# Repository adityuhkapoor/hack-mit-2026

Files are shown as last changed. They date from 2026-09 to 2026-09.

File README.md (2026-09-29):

# Nimbus

An experimental camera built at HackMIT 2026. Nimbus keeps the photographed
subject unchanged while using light, temperature, motion, sound, and weather
data to generate a new setting around them.

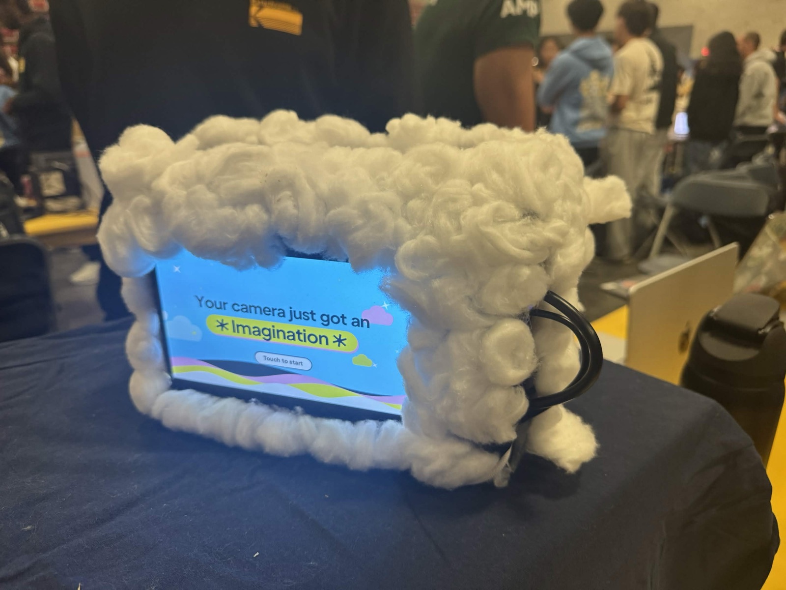
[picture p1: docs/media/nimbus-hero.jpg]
Nimbus running at HackMIT 2026


**[Watch the demo](https://youtu.be/b3_kws8iIpU)** ·
**[Instagram](https://www.instagram.com/nimbus_hackmit2026/)** ·
**[Web interface](web/)**

The prototype runs across a Raspberry Pi 4, an Arduino UNO Q, and an ASUS
Ascent GX10. It supports voice capture, searchable photo metadata, QR sharing,
printing, and pixel-level verification that the protected subject was preserved.

The app has two modes:

- **AI Camera:** takes a photo, chooses a design based on what's in it, and sends it
  to a GPU server to generate the result. The pipeline uses a subject mask to keep
  the selected subject from the original photo while changing the area around it.
- **Visa Buy:** takes an unedited photo, identifies the item or dish, and searches
  for shopping options. The app includes a Visa checkout flow; purchase completion
  is not covered by our current hardware tests.

You can browse saved photos, search them by voice or text, and open a photo link
on your phone by scanning a QR code. Voice, sharing and Instagram posting require
their respective services and credentials. Automatic Instagram posting is enabled
by default; set `NIMBUS_AUTO_POST=0` for testing.

The Raspberry Pi runs the screen and webcam. An Arduino UNO Q supplies thermal
readings and button input, and an ASUS GPU computer processes AI captures over
the network. Sensor readings are included with captures; the current AI Camera
mode chooses its design from the photo's content.

## Repository guide

| Where | What |
|---|---|
| [docs/BUILD_LOG.md](docs/BUILD_LOG.md) | Photos and notes from loose electronics through the HackMIT prototype and printable enclosure design |
| [docs/DESIGN.md](docs/DESIGN.md) | Original design notes, including earlier mode names and sensor-effect concepts |
| [TEAM_HARDWARE_RUNBOOK.md](TEAM_HARDWARE_RUNBOOK.md) | **Hardware handoff**: touchscreen wiring, camera bring-up, board roles, ASUS/Pi networking, verified behavior, and open gaps |
| [device/](device/) | The camera app (voice, screen, d-pad, tagging, search). Runs on the Raspberry Pi rig; Mac development and legacy UNO Q mode are also supported |
| [pipeline/](pipeline/) | The image pipeline and API (`nimbus`), deployed on the GPU box |
| [infra/elastic/](infra/elastic/) | Elasticsearch for photo search |
| [docs/HANDOFF.md](docs/HANDOFF.md) | Deployment handoff notes; check dates before relying on host or service status |
| [docs/TRACKS.md](docs/TRACKS.md) | Sponsor tracks: what to show a judge for each, and the demo order |
| [docs/demo/](docs/demo/) | Demo renders |

Quick start on a Mac: see [device/README.md](device/README.md) (`uv run python -m nimbus_cam --mac`).

Never commit credentials, Tailscale authentication links, Wi-Fi passwords,
camera tokens, or private user photos.

## Current rig and performance

The Raspberry Pi 4 runs the touchscreen app and USB C270 webcam. The Arduino UNO Q
provides thermal readings and buttons; the ASUS GPU computer runs the AI service.
See [device setup](device/README.md) and [network recovery](device/NETWORK_RECOVERY.md).

The tested Pi launcher selects the SDL2 presenter at a 24 FPS target. Steady home-screen
callback throughput measured approximately 23.9–24.0 FPS; capture/review transitions
still have occasional hitches. This is app callback throughput, not measured display
scanout or camera-to-screen latency. A fresh checkout defaults to Tk at 15 FPS until
configured. See [measurements and limitations](device/FRAME_PACING_RESULTS.md).

An intermittent capture error (`Server disconnected without sending a response`)
remains under investigation. Experimental camera buffering changes are not on main
and have no verified hardware speedup yet.

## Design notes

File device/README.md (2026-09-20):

# Nimbus camera app

The current rig uses a Raspberry Pi 4 for the Python app, touchscreen and USB webcam,
an Arduino UNO Q for thermal readings and buttons, and an ASUS GPU computer for AI
capture processing. Mac development uses simulated sensors. The older standalone
UNO Q App Lab files (`sketch/`, `python/`, `app.yaml`) are a legacy path, not the
current Pi deployment instructions.

## The rig (Raspberry Pi 4 + Arduino UNO Q + C270 + 1024x600 touch panel)

| Part | Where | Feeds |
|---|---|---|
| MLX90640 thermal array | behind the UNO Q, I2C `0x08` (12 chunks, ~3 fps) | temperature → hue, frame change → motion → blur |
| C270 webcam | USB | the picture, and the light level → grain |
| C270 microphone | USB (ALSA card 3) | sound → saturation, and your voice |
| Speaker | the Pi's 3.5 mm jack (or HDMI) | the camera's voice |
| Touch panel | HDMI + USB touch | the screen and its buttons |
| Local weather | Open-Meteo | humidity → diffusion, wind, cloud (labelled "(web)") |

**The four buttons** are on the **UNO Q's** digital pins (active-low to ground; the sketch enables the
pull-ups) and reach the Pi over the same I2C link as the thermal array (command `0x07`, see
[unoq/nimbus_unoq.ino](unoq/nimbus_unoq.ino)). The Pi names them with
`NIMBUS_BUTTONS="shutter=4,mode=5,talk=6,browse=7"` and turns them on with `NIMBUS_I2C_BUTTONS=1`:

| Button | Does |
|---|---|
| `shutter` (D4) | take a photo |
| `mode` | switch mode: AI Camera ⇄ Visa Buy |
| `talk` | hold to speak to the camera |
| `browse` | next photo / open the gallery |

Only D4 is named so far. **A press on an unnamed pin is logged** (`[buttons] unnamed pin D9 pressed`) — press
each button once while watching `~/nimbus-run.log`, put the numbers in `NIMBUS_BUTTONS` in
`~/start_nimbus.sh`, and restart. The configured labwc autostart calls that launcher. (Buttons straight on the Pi's GPIO still
work too: `NIMBUS_GPIO=1`, `NIMBUS_PINS="shutter=17,mode=27,talk=22"`.)

### Reflashing the UNO Q

There is no Arduino IDE in the loop: the sketch is built and flashed **from the UNO Q's own Linux**, reached
over ADB from the Pi (the board is on the Pi's USB).

```bash
ssh pi
adb shell                                                    # user: arduino
arduino-cli lib install "Adafruit MLX90640"                  # once
python3 patch_mlx90640.py ~/Arduino/libraries/Adafruit_MLX90640/Adafruit_MLX90640.cpp   # once, see unoq/patches
cd ~/nimbus_unoq && arduino-cli compile --fqbn arduino:zephyr:unoq . \
  && arduino-cli upload --fqbn arduino:zephyr:unoq -p 192.168.8.122 --upload-field password=arduino .
```

(`adb push` the sketch and the patch script from the Pi first; the upload address is the board's own wlan0,
`arduino-cli board list` prints it.) The MCU restarts ~30 s after the upload finishes. Its `Serial` output is
`/dev/ttyACM0` on the Pi: `sudo timeout 5 cat /dev/ttyACM0` shows frames and `buttons=0x..` on every press.

**Why the patch:** the Zephyr core's `Wire` always sends a STOP after the address write, and the MLX90640
needs a repeated start, so every read came back from the wrong address and every pixel was NaN. The patch
makes the driver read through Zephyr's `i2c_write_read()`.

## Run the camera on a Mac (no hardware needed)

```bash
(cd infra/elastic && docker compose up -d)          # photo search (optional: falls back to a local index)
cd device && uv sync
uv run python -m nimbus_cam.agent                # once: creates the ElevenLabs agent (needs both keys)
uv run python -m nimbus_cam --mac                # screen + voice + webcam + simulated sensors
```

| Mode | Command |
|---|---|
| A still instead of the webcam | `--image ../pipeline/eval/photos/64.jpg` |
| Type to the camera (Muse, no mic, no ElevenLabs) | `--text` |
| Tools only, no screen: a test script | `--script "fog; take_photo; wait; search_photos query=fog"` |
| Skip Elasticsearch | `--local-library` |

Keys: ←/→ mode · space shutter · **hold T to talk** · ↑/↓ browse · P send to phone (QR code) · I post to Instagram · R print (or the PRINT button on the photo screen) ·
Esc viewfinder · F/H simulated fog/heat.

On macOS, secrets can come from Keychain or environment variables. On the Pi, the configured launcher sources the existing `/etc/nimbus.env`; keep it and the local voice-agent configuration out of Git.

| Keychain service | Environment variable | Status |
|---|---|---|
| `meta-model-api-key` | `MODEL_API_KEY` | required for model calls |
| `elevenlabs-api-key` | `ELEVENLABS_API_KEY` | needed for voice |
| `ig-token` | `IG_TOKEN` | needed to post (the account id is looked up from it) |

```bash
security add-generic-password -s elevenlabs-api-key -a $USER -w '<key>' -T /usr/bin/security -U
```

Tests: `uv run pytest` (offline; no keys, models or network needed).

Instagram needs a professional (business or creator) Instagram account and one token from the Meta app dashboard (Instagram API with Instagram Login). Check it with `uv run python -m nimbus_cam.instagram`. Token scope:
`instagram_content_publish`. The card image is what gets posted.

## On the Pi rig (Raspberry Pi 4 + Arduino UNO Q + C270)

```bash
rsync -a --exclude .venv --exclude .git ./ raspi4:~/nimbus/     # from the repository root; requires your SSH alias
ssh raspi4 'cd ~/nimbus && python3 -m venv .venv && .venv/bin/pip install -e pipeline -e device'
ssh raspi4 'sudo apt-get install -y libportaudio2'      # the webcam microphone
ssh raspi4 'cd ~/nimbus/device && NIMBUS_SEG=human ../.venv/bin/python -m nimbus_cam --pi'
```

`--pi` reads the MLX90640 thermal array through the UNO Q on I2C 0x08 (temperature, and motion from the
change between frames), the light level from the camera frame, and sound from the webcam microphone.
Humidity, wind and cloud come from the local weather and are labelled "(web)" on the card.
`NIMBUS_SEG=human` picks the light segmentation model, which the Pi can actually run.

Before using the Elasticsearch library, download and verify its search model while
the network is available:

```bash
cd device
uv run python -c 'from nimbus_cam.library import embed; print(embed(["setup check"]).shape)'
```

The model stays in `~/.nimbus/camera/models` (or `NIMBUS_EMBED_CACHE`), survives
reboots, and loads offline when cached. Run this as the camera user with the same
`NIMBUS_CAM_HOME` setting as the app. A missing model still requires a first download;
capture currently waits for library indexing before showing review.

## Tested touchscreen configuration

The touchscreen starts on the animated Nimbus welcome screen. Touch anywhere to
enter the camera through a parting cloud curtain; that touch does not take a photo.
The clouds wait briefly for a fresh preview frame, with a bounded timeout if the
camera is unavailable. The **IDLE** button in the
top-right corner of the viewfinder returns to the welcome screen. While idle,
preview decoding and shutter actions are paused. The camera connection and other
app services remain initialized for quick resume. Set `NIMBUS_START_IDLE=0` to
start directly in the viewfinder for automated capture tests. Script mode is
unaffected. The IDLE button is unavailable during capture.

The existing Pi deployment uses `~/start_nimbus.sh`, called by labwc autostart.
It selects `NIMBUS_UI_BACKEND=sdl`, `NIMBUS_UI_FPS=24`,
`SDL_VIDEODRIVER=wayland` and `NIMBUS_UI_FRAME_STATS=1`. The SDL presenter must
be [built separately](native_presenter/README.md); installing Python packages
alone does not build it. Tk is still needed for the event loop. SDL initialization
failure falls back to Tk. Without configuration the source defaults to Tk at 15 FPS.

Measured steady home-screen callback throughput was roughly 23.9–24.0 FPS.
Transitions can still hitch; these measurements do not establish physical display
FPS or webcam latency. See [full results](FRAME_PACING_RESULTS.md).

The configured Pi uses `NIMBUS_API=http://127.0.0.1:18000` and
`NIMBUS_ES_URL=http://127.0.0.1:19200` through its persistent SSH tunnel to ASUS.
These endpoints require the tunnel and its separately provisioned keys; they do
not work on a fresh machine just by setting environment variables. See
[network recovery and verification](NETWORK_RECOVERY.md). The Pi and ASUS can
use different networks if both can reach their tailnet.

Automatic Instagram posting defaults to enabled. For capture QA, set
`NIMBUS_AUTO_POST=0` in the process environment after loading configuration.
An intermittent `Server disconnected without sending a response` capture failure
remains unresolved. Camera-buffer experiments are not included in main.

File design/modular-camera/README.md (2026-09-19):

# Nimbus modular camera — mechanical prototype R01

Printable modular chassis around the existing screen holder. Designed for the HackMIT Bambu A1 / P1S machines listed at <https://hardware.hackmit.org/3d-prints>: 256 × 256 × 256 mm, 0.4 mm nozzle, PLA (checked September 19, 2026). **Nothing has been submitted for printing.**

## What this is

A roomy, serviceable assembly: rear screen frame, floor, two open sides, removable roof, replaceable webcam front, electronics shelf, webcam cradle, battery cradle, and interchangeable sensor carriers. Separate parts join with through-bolts and nuts. These are **not snap-fit joints**. The old screen-holder R02 is reused unchanged; do not print another if you already have it.

Main shell: approximately **224 W × 188 D × 180 H mm**, before protruding sensors, fasteners, screen washers and cables. This prioritizes hackathon access and modularity over a compact polished camera. Open sides are deliberate cable/service openings, not a sealed or drop-resistant enclosure.

In scope:

- Rear touchscreen, using your measured body and mounting-tab dimensions.
- Raspberry Pi **4B** and Arduino UNO Q, both accommodated on one removable shelf. Either can be omitted. Mechanical accommodation does not establish their software roles or electrical compatibility.
- Anker **A110D** power bank, removable and strapped at the bottom.
- Logitech **C270**, retained with its original clip and adjustable straps/padding.
- Up to five external sensor/control carriers: proposed roof Buttons, Light, Movement; front Distance and thermal/spare. Only install modules you actually need.

Not included: ESP32 / BOX-3 (explicitly removed), internal ASUS, printer, TP-Link hub, or a speaker. ASUS can remain external/networked. The Logitech has a microphone, not a speaker; voice output needs a separate later provision.

## Files

- `nimbus-modular-camera.blend`: assembled editable Blender model, including clearly named reference hardware.
- `build.py`: parameterized Python construction source for Blender 5.2; millimetres. Run `blender -b --python build.py` from an extracted package. `inputs/` contains the original screen-frame/washer meshes needed to rebuild.
- `stl/`: **only printed parts**, individually exported in intended print orientation. No electronics are included in these STLs. Import at 100%, millimetres.
- `PRINT_MANIFEST.md`: exact copies and exported dimensions.
- `ASSEMBLY.md`: staged print and assembly instructions, fasteners and outstanding checks.
- `SOURCES.md`: sources, measurements and assumptions.
- `print-manifest.json`: per-part manifold, connected-solid, volume, triangle and dimension checks.
- `clearance-checks.json`: rigid-part and reference-envelope interference checks.
- `mounting-coordinates.json`: the board and screen interface coordinates.
- `assembled-front.png`, `assembled-rear.png`, `cutaway.png`, `exploded.png`: CAD renders, not photos of an assembled device. Colored blocks are approximate hardware envelopes; logos/text are reference-only and are not embossed in the printable meshes.

This is mesh-based CAD with a reproducible generator, not a STEP/B-rep model. Package includes the `.blend`, source, STLs, documentation, references and renders.

## Validation and limits

Every exported part passed checks for a single connected solid, zero non-manifold edges, positive volume, a nonempty binary STL and dimensions within 0.002 mm of the source mesh. Every individual part fits the published printer volume. Modeled mating parts and conservative hardware envelopes show no solid intersections above the script's 0.1 mm³ reporting threshold.

**Physical fit, load strength, cable bending, slicer behavior, print duration, cooling and the complete power budget are not validated.** The model is ready for a staged fit prototype, not an assertion that all hardware can be enclosed and battery-powered without further testing. Start with the screen frame and hole coupon, not an unattended full print batch.

## Electrical scope is unchanged

This enclosure does not solve power distribution. The photographed A110D label gives a combined **5 V / 3 A (15 W)** output limit in multi-port use. Do not infer the complete Pi + UNO Q + screen + camera system can run from it merely because all components fit. Leave wall-power options accessible and test the intended wiring under load before relying on battery operation. No improvised battery wiring, GPIO power feeds or USB power backfeeding are part of this design.

Boards need insulating spacers, connectors need strain relief, and the power bank must remain removable without being squeezed. Keep ventilation clear. Do not use this prototype as a load-bearing shoulder-strap case until the assembled joints have been checked under the actual weight.

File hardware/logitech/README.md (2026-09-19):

# Logitech C270 camera module — Mac bench prototype

This is Aditya's tested local Camera Studio prototype, published separately from
the existing Nimbus `device/`, `pipeline/`, and `web/` apps. It does not replace
them or claim that their hardware integration is complete.

## What is included

- `server.py`: Logitech capture backend (`Camera`), localhost HTTP API, original
  capture storage, gallery, local effects, optional provider hooks.
- `web/`: preview, touch-friendly shutter, rotate/mirror, effect selection,
  original/result comparison and downloads. Spacebar can trigger capture.
- `arduino_link.py`: optional UNO Q discovery over ADB and capture LED feedback.
  This is not physical shutter firmware or a sensor driver.
- Tests, dependency list and a credential-free `.env.example`.

No real captures, API keys, firmware dumps, personal photos or account credentials
are included. Local `captures/` and `.env` files are ignored.

## Run on macOS

Requirements: Python 3.10+, FFmpeg with AVFoundation support, and a USB-connected
Logitech C270. The implementation currently uses AVFoundation, not Linux V4L2.
Install FFmpeg with your normal package manager if absent. ADB is optional.

```sh
cd hardware/logitech
python3 -m venv .venv
source .venv/bin/activate
python3 -m pip install -r requirements.txt
python3 server.py
```

Open <http://127.0.0.1:8765>, grant macOS camera access to the process that requests
it, and click Connect camera. If another camera app owns the camera, close it.
The default device name is `C270 HD WEBCAM`; set `CAMERA_NAME` in the environment
or a local `.env` if the device is named differently. `PORT` can override 8765.
There is no need to create `.env` or configure cloud credentials for local use.

The backend requests 1280x720 at 30 fps; this is a requested mode, not a guaranteed
achieved rate. The existing `preview_fps` status field is hard-coded, and the UI
polls JPEG frames every 250 ms. Do not use that field as a measured frame rate.

## Verification and limitations

```sh
python3 -m unittest test_server.py test_arduino_link.py
```

All 10 tests passed when published. They use synthetic images/mocked hardware;
they do not establish fresh USB, touchscreen, cloud API or Pi compatibility.
Earlier physical bench testing demonstrated C270 live capture on the Mac.

- Linux/Pi/UNO Q camera hosting still needs a V4L2 (or equivalent) backend.
- Local Enhance/Noir/Dream/cards are local image processing, not generative AI.
- OpenAI editing and ElevenLabs speech hooks are unverified. The inherited image
  model setting is not validated; explicitly configure a supported model before
  enabling provider calls. Supplying keys and using those actions sends image/
  prompt or text to the provider and may incur costs. Speech plays on the browser
  host; this does not provide BOX-3 speaker transport.
- With no speech API key, browser speech synthesis may be used; behavior and
  offline support depend on the browser/OS voice engine.
- The UNO Q adapter polls ADB devices for the UNO Q user-LED interface and, on
  capture, briefly writes that LED only if its trigger is `none`, then restores
  brightness. No sketch is flashed. Disconnect the board/omit ADB if undesired.
- `/api/sensors` is an ingestion boundary only. No physical sensor readings or
  shutter input are implemented here; stale readings are omitted.
- Preview stays in RAM until explicit capture. Captured originals and edits are
  stored locally. A watchdog releases the camera after 90 seconds without camera
  activity; status polling alone does not count as frame activity.
- Localhost binding, Host/Origin checks and a per-process action token are present.
  They are not remote-service authentication. Do not change the bind address or
  expose this prototype directly to venue Wi-Fi/the internet.

## Integration boundary

Reuse `Camera.start()`, `snapshot()`, `status()` and `stop()` as the initial
acquisition contract. Keep the platform-specific FFmpeg command behind this
boundary when adding Linux support. `capture()` preserves the original and
freezes available sensor values; both future physical-shutter and UI events
should invoke the same serialized capture action.

GET routes: `/api/status`, `/api/frame`, `/api/gallery`.
POST routes: `/api/camera/start`, `/api/camera/stop`, `/api/capture`, `/api/render`,
`/api/sensors`, `/api/speech`. POST calls require `X-Camera-Token` from the local
page's `camera-token` meta element. Prefer the included UI for bench testing.

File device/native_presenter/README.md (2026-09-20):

# Nimbus native presenter prototype

This opt-in prototype keeps Nimbus rendering in Python/Pillow and replaces only
the final Tk image handoff with a persistent SDL2 streaming texture. `nimbus_cam.ui` integrates it when
`NIMBUS_UI_BACKEND=sdl` is set, and falls back to Tk if initialization fails.
The tested Pi launcher targets 24 FPS with `NIMBUS_UI_FPS=24` and
`SDL_VIDEODRIVER=wayland`; generic defaults remain Tk and 15 FPS.

Build on a machine with SDL2 development headers:

```bash
cd device/native_presenter
cmake -S . -B build -DCMAKE_BUILD_TYPE=Release
cmake --build build --config Release
```

Debian/Raspberry Pi OS provides the headers in `libsdl2-dev`. Installing that
package on the camera is deliberately outside this prototype. Existing runtime
libraries alone are not enough to compile it.

Run the deterministic benchmark after building:

```bash
cd device
uv run python tools/bench_native_presenter.py --hidden --fps 15 24 30
```

`--hidden` is useful for automation and can select SDL's software/dummy path;
the JSON always reports the renderer and its acceleration flags. A useful
hardware result must use the real display driver without `--hidden` or
`SDL_VIDEODRIVER=dummy`.

The creator thread owns the SDL window, texture, event queue, and shutdown.
The same thread must call every presenter method. Frames are RGB24 with a
validated size, stride, and buffer length. One window, renderer, and streaming
texture live for the entire presenter lifetime.

The event API currently covers pointer press/release, keyboard press/release,
and quit. It maps mouse and normalized finger positions through the same
aspect-fit letterbox used for rendering and returns logical 1024x600
coordinates plus an `inside` flag. The UI routes those events through the existing touch/key actions, including
release handling and focus-loss cancellation. Hardware acceptance remains
separate from unit coverage; see [results](../FRAME_PACING_RESULTS.md) for what
was measured. Tk still owns the application event loop; SDL presents the pixels.

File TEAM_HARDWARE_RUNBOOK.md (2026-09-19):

# HackMIT camera: teammate hardware and interface runbook

Status snapshot: **September 19, 2026, approximately 6 PM Eastern**. This is
the handoff for the currently tested physical camera path. It distinguishes
observed behavior from planned integration. Do not put Wi-Fi passwords,
device passwords, API keys, Tailscale auth links, or camera-token values in
this repository.

## Demo architecture

```text
Logitech C270 --USB----------------------+
Wisecoco 7-inch display --HDMI----------+|  camera host
Wisecoco touch --USB--------------------+|  Mac: proven baseline
UNO Q controls/sensors --USB (planned)--+|  Pi: standalone target
ESP32-S3-BOX-3 voice --USB serial-------+|       |
                                               +-- network --> ASUS GX10 / cloud AI
```

The core demo is **preview -> capture -> preserve original -> optional edit ->
compare/save**. Printing is deferred. A local effect must not be presented as
a generative-AI edit. The original capture remains immutable.

## What has actually passed

- Logitech C270 live preview and capture on macOS at 1280 x 720 (observed
  preview around 10 fps).
- Browser camera UI on the large HDMI display, including touch input.
- Repeated local capture, original preservation, local enhancement, gallery,
  and download. The current Python test suites passed during development.
- UNO Q USB/ADB detection and reversible green user-LED acknowledgement after
  capture. This is **not** yet a physical shutter.
- ESP32-S3-BOX-3 factory display, touch, speaker, wake word, and offline
  command recognition. Live serial observation identified factory phrase
  `Sing a song` as command/phrase ID 8 twice. The host adapter can map an
  explicitly armed/allowlisted recognition event to the same capture API.
- ASUS Ascent GX10 first boot, Wi-Fi, SSH, Tailscale, NVIDIA GB10 visibility,
  and Python environment. CUDA PyTorch 2.14.0+cu130 installed; the later
  ComfyUI dependency step was deliberately paused during a network handoff.
- Raspberry Pi hostname `raspi4`, 64-bit Debian 13/Raspberry Pi kernel, and
  SSH were verified through the ASUS while both were on the same temporary
  hotspot. Pi Tailscale installation/authentication was **not completed** at
  this snapshot.

## Large touchscreen wiring

The rear board is labeled `Wisecoco USB-Touch 7inch-TTL HDMI-Display`.

| Display label | Connect to | Purpose |
|---|---|---|
| `HDMI-IN` | Host HDMI output | Video |
| `5V+Touch` | USB **data** port on the powered hub/host | Touch data and 5 V |
| `+5V-IN` | Leave unused for the known-good bench setup | Separate 5 V input if the exact display/power arrangement requires it |

Important:

- HDMI does not carry touch; the `5V+Touch` data cable is required.
- Use a powered hub **data port**, not one of its charge-only ports.
- Do not feed the display from two 5 V sources unless the exact board/manual
  confirms that arrangement. Stop if the panel flickers or resets.
- Keep the exposed PCB on an insulated surface or standoffs.
- Upright assembly convention: while facing the screen, its HDMI/USB ports are
  on the user's right. After rotation, verify both image orientation and touch
  coordinates.

### Known-good Mac connection check

```sh
system_profiler SPDisplaysDataType SPUSBDataType
```

Expected evidence includes an online 1024 x 600 external display and a USB
device named `TouchScreen`. A USB device appearing proves enumeration, not
correct touch mapping; tap all corners as a separate check.

## Camera application

From the repository root on the Mac baseline:

```sh
python3 -m unittest test_server test_arduino_link -q
python3 server.py
```

Open <http://127.0.0.1:8765>, connect the camera, and move the Chrome window to
the external display using **Window -> Move to Display**. The service binds to
localhost intentionally. Do not expose it directly on event Wi-Fi; POST routes
use a per-process token embedded in the served page.

Current API boundaries used by hardware adapters:

- `GET /api/status` -- camera, sensor, and board health
- `GET /api/frame` -- latest fresh JPEG frame
- `POST /api/capture` -- save a new original
- `POST /api/render` -- create a separate edit
- `GET /api/gallery` -- recent manifests

The camera backend currently uses macOS AVFoundation/ffmpeg. Linux/Pi capture
must be implemented and accepted before calling the Pi deployment complete.

## Board roles

### UNO Q

Role: physical shutter and selected real sensors after the MCU-side interface
is implemented. The current host link only verifies USB/ADB and LED feedback.
Do not claim sensor integration, and do not invent readings when no fresh
sensor packet exists. Confirm pinout, 3.3/5 V compatibility, ground, and actual
button/sensor modules before GPIO wiring.

### ESP32-S3-BOX-3

Role: optional offline command input, later microphone/speaker endpoint. A
local prototype adapter passively observes serial data; it does not flash
firmware or write serial data. That adapter is not yet part of this shared
repository, so ask the hardware owner for the current tested copy rather than
recreating it from this status note.

Serial device numbers change after reconnect. Re-identify the Espressif USB
JTAG/serial device instead of copying an old path. The factory firmware has no
`Take a photo` phrase; its English list controls lights, colors, music, and air.
ID 8 (`Sing a song`) was used only as a temporary shutter mapping. Its observed
confidence was low (about 0.30 and 0.14), so do not silently deploy a permissive
threshold. A real phrase requires building and flashing custom firmware, with a
documented rollback image and explicit hardware ownership.

### ASUS GX10

Role: external AI worker, never mechanically inside the camera. Use its saved
Tailscale hostname rather than publishing tailnet IPs. Keep `HackMIT.2026` as
the preferred/autoconnect Wi-Fi profile. A temporary iPhone-hotspot profile was
created only to reach the Pi, with an automatic fallback intended to return the
ASUS to HackMIT Wi-Fi.

At this snapshot, CUDA PyTorch was installed into
`/home/asus/nimbus-gpu/comfyui-env`; the next `pip install -r
ComfyUI/requirements.txt` process was stopped with `SIGSTOP` to preserve work
during the network switch. Before resuming, inspect the process rather than
starting a duplicate installer.

### Raspberry Pi 4

Role: eventual standalone camera host. Existing OS and SSH work. The fastest
current bootstrap path is:

1. Put ASUS and Pi on the same temporary hotspot.
2. Reach ASUS over Tailscale from a trusted developer machine.
3. From ASUS, SSH to the Pi's private hotspot address.
4. Install Tailscale on the Pi, authenticate it to the team tailnet, enable the
   chosen SSH policy, and verify access from outside the hotspot.
5. Restore ASUS to `HackMIT.2026`; keep that profile at higher autoconnect
   priority than any temporary hotspot.
6. Change any shared/default Pi password and move to SSH keys. Share access
   privately, never through GitHub or Discord screenshots.

Do not assume that “Pi boots” means the camera app is ported. Acceptance still
requires Linux camera discovery, HDMI/touch, saved capture, restart after cold
boot, USB reconnect, and network-loss behavior.

## Teammate bring-up checklist

1. Photograph cable labels and the exact power adapters before moving hardware.
2. Verify display video and touch independently.
3. Verify the Logitech preview is fresh, then save one original and reopen it.
4. Run local enhancement and confirm the result is a separate file.
5. Check `/api/status`; absent sensors must display as absent.
6. Assign one owner per serial board before opening or flashing it.
7. On Pi, complete Tailscale and Linux camera acceptance before changing the
   enclosure around it.
8. On ASUS, resume the existing paused installer instead of launching another;
   expose AI through an authenticated job boundary with timeout/fallback.
9. Run ten capture cycles and one network-failure cycle before the demo.

## Known gaps

- No accepted Linux/Pi camera backend yet.
- No physical shutter button or debounced GPIO event yet.
- No automated generative image-edit provider wired into the UI; manual Codex
  image edits are demonstrations, not an in-app API.
- No complete microphone -> intent -> camera -> ElevenLabs -> speaker loop.
- No printer integration.
- Final enclosure power budget, cooling, cable strain relief, and measured fit
  remain integration tasks.

Mechanical screen-holder CAD notes currently exist only in the local hardware
worktree. They should be reviewed and uploaded separately; CAD geometry does
not itself prove electrical integration.

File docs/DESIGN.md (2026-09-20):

# Nimbus — software design

**The camera that photographs the air.** The person in the picture stays exactly as shot, checked pixel by
pixel. Everything around them is rendered from what the camera measured at that moment. One dial sets
how much freedom the AI gets.

Every part of the product says the same thing:

- **Dial** = how much freedom the AI gets.
- **Sensors** = what it is allowed to use.
- **Mask** = where it is allowed to act.
- **Card** = the record: the readings, and "subject unaltered · verified".

## How people use it

**Hold the button and talk to it.** The camera answers in its own voice, and the d-pad does the same things
without voice. There's no web dashboard: the only web surfaces are the shared Instagram account and the QR
code that puts a photo on your phone.

| Say | Tool | D-pad |
|---|---|---|
| "Take a picture" | `take_photo` | centre |
| "Make it a souvenir" | `set_mode` | ← → |
| "What's the air like?" | `read_air` | (always on screen) |
| "When did I take this?" / "What was the weather in this one?" | `photo_details` | |
| "Find the foggy ones from this morning" | `search_photos` | |
| "Next" / "the second one" / "back to the camera" | `show_photo` | ↑ ↓ / Esc |
| "Send this to my phone" | `send_to_phone` (QR code on screen) | P |
| "Post it" | `post_instagram` | I |

```
mic ─(push-to-talk)─► ElevenLabs agent ──custom LLM──► Muse Spark (Meta Model API, reasoning "minimal")
speaker ◄─────────── speech                  │ tool calls, executed on the camera (ClientTools)
                                             ▼
   device/nimbus_cam/app.py: the 8 tools ─► capture (below) · Muse vision tags · Elasticsearch · Instagram
```

- **Push-to-talk.** The ElevenLabs session stays open, but the mic sends silence unless the button is held, so a loud room never starts a turn.
- **Tagging.** Muse Spark looks at each photo once (~4 s, in the background) and returns a caption, tags, scene, mood, people and an Instagram line. The camera's own condition words (fog, cold, loud, haze…) are always added, so the measured air stays searchable even if the image doesn't show it.
- **Search.** Elasticsearch runs hybrid search: BM25 plus kNN on a bge-small embedding, both under the same filters (time range, mode, temperature, humidity). Muse turns speech into those filters: "foggy this morning" becomes `query=fog`, `min_rh=80`, and an ISO time window. The weather in words is weighted highest, because a photo taken in 94% humidity is a foggy photo whatever the scene shows. If Elasticsearch is down, a local SQLite + NumPy library answers the same queries.

## Sponsor tracks

| Track | How this one product hits it |
|---|---|
| **Arduino** | Sensors drive the picture. Real renders on the UNO Q itself. |
| **Meta** | Muse Spark is the brain (voice reasoning, tool calls, vision tagging, captions). Photos post to a shared Instagram account, and phones get photos by QR code. |
| **ElevenLabs** | A voice agent with real tools, a persona and push-to-talk, with Muse as its custom LLM. |
| **Elastic** | Hybrid semantic search with range filters over time and measured air. |
| **Long Lake** | Pitch: the verified-subject proof converts the photographer who distrusts AI. |
| Token Company (optional write-up) | Real uses zero tokens. Tags are computed once per photo. Reasoning is set to "minimal", which cut Muse's reasoning tokens from 228 to 87 on the same reply. |

## The two modes

One mode does everything the sensors ask for; the second is the keepsake.

| Pos | Name | Subject | Surroundings | Where it runs |
|---|---|---|---|---|
| 0 | **Nimbus** | Unchanged | FLUX.2 klein repaints the measured air into the *same* place, keeping its layout; the real background's fine texture is carried back in, less of it as humidity rises. The sensor effects go on top. | GPU |
| 1 | **Souvenir** | Unchanged | Muse names the keepsake the scene deserves (a can of Red Bull → a trading card, noodles → a ramen packet); klein paints that artwork, and a frame carries the title and the readings. | GPU |

**With no GPU reachable, the shutter still works**: the camera renders the sensor effects on its own board
and says so (`fallback_reason`). That is also the Arduino track's "no cloud" story — the degraded path is a
complete picture, not an error.

Earlier builds had four positions (Real / Sensed air / New world / Souvenir). Real and the split between
"same place" and "new place" were dropped on 2026-09-19: one sensor-driven mode is the product.

## Readings → effects

| Reading | Source | Effect on the surroundings (Real) | Words for the AI (dials 1–2) |
|---|---|---|---|
| Temperature | BME280 | Colour temperature: cold is blue, hot is amber | frost … heat haze |
| Humidity | BME280 | Diffusion: a Pro-Mist bloom, screen-blended | fog, mist, humid haze |
| Light (lux) | APDS-9930 | Grain: dim scenes get high-ISO grain | night, dusk, overcast, hard sun |
| Sound (dB) | Sound sensor | Saturation: quiet is muted, loud is vivid | calm vs energetic light (never "crowds") |
| PM2.5 | SEN54 | Haze: contrast drains toward a pale veil, more with distance | smoky or hazy air |
| Pressure | BME280 | None | a storm gathering, when low |
| Wind | **Web** (Open-Meteo) | Distortion: a barrel bend and a gust smear | breeze, strong wind |
| Cloud cover | **Web** (Open-Meteo) | None | overcast, scattered or clear sky |

- **Web values fill gaps only.** A sensor reading always wins over a web value.
- **Web values are labelled.** The card marks them "(web)", and each capture's metadata lists which values came from the web.
- **Missing sensors are neutral.** A sensor that isn't fitted leaves its effect switched off.
- **The AI dials use a lighter touch.** They scale the sensor effects down, because the model has already painted the weather.

## One shutter press

```
UNO Q MCU ── sensors, shutter, dial ──Bridge "key=value;…"──┐
UNO Q Linux: grab frame + readings ─────────────────────────┘
  │   + wind, cloud from web weather (only if missing)
  ├─ GPU reachable ─► POST /capture ─► mask ─► klein inpaint (2 MP on the GB10)
  │                  ─► real detail back in, less in fog ─► sensor effects ─► paste back ─► verify
  │                  ─► [Souvenir: mount the card frame around it]
  └─ GPU down ──────► ON THE BOARD: shrink to 2400 px while still 8-bit ─► mask ─► clean plate
                     ─► sensor effects ─► paste the real subject back ─► verify ─► POST /captures/publish
  ▼
server stores photo, as-shot, mask overlay, and draws the card (its QR code → /c/<id> → the card image)
  ▼
camera: Muse tags it · Elasticsearch indexes it · on request: QR code to a phone, or post to Instagram
```

## The honesty guarantee

`subject.py` enforces it and the tests check it:

1. **Find the subject.** Two ONNX models segment it, run directly on onnxruntime (no rembg): `isnet-general-use` for objects and what people hold, and `u2net_human_seg` for whole bodies, hands included. When a face is found, their masks are combined. On the board, `NIMBUS_SEG=human` uses the body model alone, because the 1024² general model is too slow there.
2. **Clean plate.** The subject's area is filled in before any background effect runs, so blooms and bends pull in background colour, never the subject's.
3. **Composite.** The original subject pixels go back in bit for bit. Only a 2 px edge band cross-fades.
4. **Verify.** In 8-bit, inside the mask shrunk by that edge band, the output must equal the as-shot frame exactly. The result is printed on the card and exposed as `untouched` in the API.

The only change ever made to the subject is **white balance**, and only from a real colour sensor (`cct`), as a genuine correction. None is planned for this build.

## Performance (measured)

**Where the GPU work runs (2026-09-19):** the **ASUS GB10** (`gx10-5493`, Grace-Blackwell, 128 GB unified,
Ubuntu 24.04 arm64) on the venue wifi, running ComfyUI plus the Nimbus API on port 8000. The camera posts to
`http://10.189.73.14:8000` — the venue address, because the tailnet ACL only opens port 22. The Windows box
over ZeroTier stays as a fallback (`nimbus.akvaithi.page`), but the rig cannot be on ZeroTier and the tailnet
at once, so the ASUS is the one to use at the event. Its profile is `gb10` (klein fp8 + the fp4 text encoder
it ships with); it generates at 2 MP with no upscaler, where the 3060 Ti needed 1.5 MP + ESRGAN.

| Path | Time | Notes |
|---|---|---|
| Effects-only fallback, on an M3 at 2400 px | ~1.3 s | Peak memory **1.26 GB**, flat across shots. |
| Nimbus / Souvenir on the ASUS GB10 | ~25 s | klein at 2 MP, no upscaler. Pi → ASUS → verified capture: 32 s end to end. |
| Nimbus / Souvenir on the Windows 3060 Ti | ~30 s | klein at 1.5 MP ≈ 15 s, ESRGAN ≈ 10 s, plus transfers. |
| Segmentation | 0.5 s (body), 1.0–1.4 s (general) | M3 |

## Contracts

- **MCU → Linux** (Bridge): `readings()` returns `temp_c=…;rh=…;lux=…;db=…;pm25=…;pressure_hpa=…`, any subset. `controls()` returns `shutter,dial`. `status(n)` sets the LEDs.
- **Camera → server**: `POST /capture` for dials 1–2, `POST /captures/publish` for Real rendered on the board. See [API.md](API.md).
- **Phone**: the QR code carries `/c/<id>`, which redirects to that photo's card image. There is no web dashboard.

## Code map

| Where | What |
|---|---|
| `pipeline/nimbus/sense.py` | Readings, the effect map, the effects, the prompts |
| `pipeline/nimbus/subject.py` | Segmentation, clean plate, composite, verify, mask overlay |
| `pipeline/nimbus/capture.py` | One press end to end, web-weather merge, card, capture store |
| `pipeline/nimbus/weather.py` | Open-Meteo wind and cloud cover, cached for 10 min |
| `pipeline/nimbus/api.py` | `/capture`, `/captures/publish`, `/captures…`, `/c/<id>` (→ the card image) |
| `device/nimbus_cam/app.py` | The camera's state and its 8 tools (shared by voice and the d-pad) |
| `device/nimbus_cam/{agent,voice}.py` | ElevenLabs agent setup (persona, tools, Muse as custom LLM); push-to-talk session; typed test mode |
| `device/nimbus_cam/{tagger,library}.py` | Muse vision tags; Elasticsearch / local hybrid search |
| `device/nimbus_cam/{hw,ui}.py` | Sensors, camera and push-to-talk audio; the Tk screen and d-pad |
| `infra/elastic/docker-compose.yml` | Single-node Elasticsearch |
| `device/sketch/sketch.ino` | MCU: sensors and controls over the Bridge (drivers to be finalised with the parts) |
| `device/python/main.py` | App Lab entry point (runs `nimbus_cam`) |

## Open

- **Parts.** The sensor drivers in the sketch get written once the parts are confirmed. The Bridge contract above doesn't change.
- **Camera.** The HQ camera on the UNO Q needs a MIPI-CSI carrier board. Without one, use a USB webcam.
- **Keys still missing.** The ElevenLabs key and agent, and the Instagram business account and token.
- **Test captures.** Clear the test captures on the box before judging.
- **The cut-out look.** An unchanged subject under new air can look pasted in, and that is the product's deliberate trade-off. If it has to change, the honest alternative is lens-level effects (mist, grain) over the whole frame, with the card saying "subject not generated" instead.

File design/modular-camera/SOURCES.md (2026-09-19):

# Dimensions: sources versus allowances

Checked September 19, 2026. Manufacturer mechanical drawings informed the computer mounting holes; user measurements take precedence for the unconfirmed screen assembly. Product envelope dimensions are not detailed port, clip or cable geometry.

| Component | Basis used | Confidence / remaining issue |
|---|---|---|
| Touchscreen | User: 6.5 in / 165.1 mm long, final short-side measure about 100.5 mm, 124 mm including ears, holes about 156 × 115 mm; tab holes less than 3 mm | Approximate physical measurements. Generous opening and slots compensate; test fit required. Rear 20 mm keepout is a design allowance, not verified rear-stack maximum. |
| Raspberry Pi 4B | 85 × 56 mm PCB; 58 × 49 mm hole pitch with asymmetric long-edge placement | Official drawing. Model uses original 3.5 mm edge offsets and rotates board 180°. Cooler height/actual plugs not measured. |
| UNO Q | 68.58 × 53.34 mm PCB; four individual hole coordinates | Official drawing, not a guessed rectangular pattern. 25 mm vertical allowance is not measured height. |
| Logitech C270 | W72.91 × D66.64 × H31.91 mm including clip | Official product sheet envelope. Articulated clip changes pose; padded/strapped adjustable support, no precision fitted lens ring. |
| Anker A110D | 140.7 × 71.7 × 15.4 mm | Manufacturer model page. Leads/plug bends are additional. Multi-output power limit taken from photographed actual label. |
| Modulino-style sensors | Example 41 × 25.36 mm PCB, nominal 32 × 16 mm holes | Buttons drawing provides hole footprint. Repeated reference rectangles are planning envelopes, not exact models for all five boards. Thermal breakout footprint unverified. |
| Print volume/material | 256 mm cubed, Bambu A1 and P1S, 0.4 mm nozzle, PLA | Actual authenticated HackMIT 3D print page; no job submitted or sliced. |

## Primary references

- Pi 4 mechanical drawing: <https://pip-assets.raspberrypi.com/categories/545-raspberry-pi-4-model-b/documents/RP-008343-DS-1-raspberry-pi-4-mechanical-drawing.pdf>
- UNO Q datasheet, mechanical drawing: <https://docs.arduino.cc/resources/datasheets/ABX00162-datasheet.pdf>
- Logitech C270 product sheet: <https://www.logitech.com/assets/46735/4/hd-webcam-c270.pdf>
- Anker A110D manufacturer product page: <https://anker.com.sg/products/anker-zolo-powerbank-10000mah-22-5w-power-bank-fast-charging-compact-portable-charger-with-built-in-usb-c-cable-a110d>
- Modulino Buttons: <https://docs.arduino.cc/resources/datasheets/ABX00110-datasheet.pdf>
- Modulino Light: <https://docs.arduino.cc/resources/datasheets/ABX00111-datasheet.pdf>
- Modulino Movement: <https://docs.arduino.cc/resources/datasheets/ABX00101-datasheet.pdf>
- Modulino Distance: <https://docs.arduino.cc/resources/datasheets/ABX00102-datasheet.pdf>
- HackMIT 3D printing: <https://hardware.hackmit.org/3d-prints>

Screen listing found earlier: <https://www.amazon.com/dp/B0BRMWMK6X>. Listing image: <https://m.media-amazon.com/images/I/61lyOJbuF-L._AC_SL1247_.jpg>. These do **not** replace a verified mechanical drawing of your unit; screen orientation and the right-side connectors were confirmed from your physical photos (IMG_7714–7716).

## Exact board-hole convention

Pi drawing: board X = 0…85, Y = 0…56. Holes at X = 3.5, 61.5 and Y = 3.5, 52.5 mm. The CAD translates and rotates this pattern with the board; see `mounting-coordinates.json` for assembly coordinates.

UNO Q drawing, coordinates from left/top board edges in millimetres:

- (15.24, 2.54)
- (13.97, 50.80)
- (66.04, 17.78)
- (66.04, 45.72)

The generator converts this top-edge convention to Cartesian Y and rotates the board 180°. The footprint is not a symmetric four-corner pattern.

## Assumptions deliberately visible

- Assembly uses through-bolts/nuts, not embedded inserts or untested printed snap hooks.
- Rigid envelope checking excludes cables, fasteners, tiny board components, connector protrusion and articulated clip geometry.
- Component volumes are planning blocks; renders are not scan-derived replicas.
- Screen slots accept approximate alignment; they do not make large screws safe for small PCB tab holes.
- Neither a housing fit nor a supplier power rating demonstrates that the complete device is powered correctly. The Anker's combined 15 W label limit remains an independent integration constraint.

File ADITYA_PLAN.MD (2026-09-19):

# Aditya's Camera Plan — HackMIT 2026

Status snapshot: September 19, 2026. This is the team's implementation and assembly plan, not a claim that every feature is already working. Hardware in hand, reservation requests, working software, and proposed integrations are deliberately separated below.

> **Live handoff:** Read [TEAM_HARDWARE_RUNBOOK.md](TEAM_HARDWARE_RUNBOOK.md)
> first for the later verified touchscreen, BOX-3, ASUS, and Raspberry Pi
> status. This longer plan preserves design context, but some live-state claims
> below predate the evening integration tests.

### Read alongside the existing Nimbus plan

The shared repository already contains [Nimbus design](docs/DESIGN.md), [device software](device/README.md), and an [image pipeline](pipeline/README.md). This document records **Aditya's physical hardware/integration track** and its observed tests; it does not replace those documents or audit all of their implementation claims. The local Mac prototype described below is a separate working tree and has not been uploaded as part of this documentation change.

Resolve these differences before merging implementations:

- **Brain:** existing Nimbus docs choose UNO Q as the complete camera host; this hardware discussion chose Pi as the standalone target with UNO Q for controls/sensors. Select one after camera/display/audio tests; do not maintain two production hosts by accident.
- **UI:** Nimbus describes its device UI with d-pad/voice, while this prototype uses a touchscreen browser interface. The large touchscreen remains the desired physical display; choose which app drives it.
- **Product differentiation:** retain Nimbus's sensor-driven Real / Sensed air / New world modes and protected-subject proof as candidate shared experience. Pixel-level subject preservation must be tested on the actual deployed pipeline before claiming it in the live demo.
- **Software reuse:** Nimbus already documents Muse reasoning/tagging, ElevenLabs tools, search, QR sharing and optional Instagram publishing. Reuse and verify those modules rather than rebuilding them merely because the local hardware prototype has not integrated them. Existing design documentation is not proof they all work on the currently connected boards.
- **Privacy:** social posting remains an explicit user action; no automatic publication of captures. Sponsor alignment in existing docs is a pitch plan, not verified prize eligibility.

## 1. What we are building

A physical, interactive AI camera: compose a shot on a touchscreen, trigger it from the screen or a physical control board, optionally ask for an AI transformation, compare the original and result, and save the chosen image. The camera should eventually hear requests and speak feedback using ElevenLabs. The experience should make AI's value tangible through a clear before/after, rather than a hidden filter presented as AI.

Build the reliable camera and modular enclosure first. Add AI, voice, and selected sensor capabilities through stable software interfaces without rebuilding the hardware. Do not require every borrowed board to be installed.

The target standalone camera brain is the Raspberry Pi. The Mac is the proven development/demo host while the Pi port is tested. The ASUS is optional external AI compute, not a prerequisite for the camera working.

### Target user flow

1. See a fresh live preview on the large touchscreen.
2. Choose framing/orientation and a mode; use touchscreen or physical shutter.
3. Capture and preserve the original image, with a snapshot of any real, fresh sensor data.
4. Keep the original, apply a clearly labeled local effect, or explicitly request AI enhancement/transformation.
5. Show progress and an actionable error if the network/provider fails; never lose the original.
6. Compare original and edited output, then save/download the desired result.
7. Optional voice: speak an adjustment and receive brief spoken confirmation or feedback.

Printing is deferred. Later it can consume the same saved original/edited artifact; it must not be a dependency of capture or editing.

## 2. Scope and priorities

| Priority | Deliverable | Completion criterion |
|---|---|---|
| P0: dependable photo loop | Logitech preview, touchscreen capture, original preservation, gallery/save | Works repeatedly without cloud access; no stale frames presented as current |
| P0: standalone target | Run the photo loop on Pi with display, touch, camera, storage, power, and networking | Cold boot into usable camera UI without Mac; camera disconnect/reconnect is recoverable |
| P1: physical interaction | One deliberate shutter input from the control-board module; visible feedback | One press gives one capture; debounce, disconnect, and duplicate-event behavior tested |
| P1: AI wow factor | Opt-in generative image edit, clear before/after and provider/error state | One real captured image edited end-to-end; original retained; no local filter mislabeled generative AI |
| P1: spoken feedback | ElevenLabs response through an actual tested output path | A generated response is audibly played after a camera action |
| P2: voice control | BOX-3 push-to-talk microphone input and playback, then selected commands | Speech request routes to correct action and response; mute/stop available |
| P2: meaningful sensors | Only sensors that improve a demonstrable interaction | Real data with units/freshness; sensor absence does not break the camera |
| Stretch | ASUS-hosted AI, richer conversation, thermal overlay, additional camera/sensor modes | Added only after base loop is stable; each has separate verification |
| Deferred | Thermal printing | Matching printer, paper, power, data connection and output quality verified first |

No requirement for custom PCB, battery operation, soldering, every available sensor, or a Pi camera replacement. Sensor overlays and voice commands are not automatically integrated merely because compatible boards are present.

## 3. Hardware inventory and evidence

“Tested” means the specific behavior listed, not complete product integration. Connection state can change as parts move between machines.

| Part | Known state | Planned role / remaining check |
|---|---|---|
| Logitech C270 USB webcam | In hand; Mac live capture tested at 1280 × 720, observed around 10 fps | Baseline camera. Verify Linux capture on Pi; keep it until an alternative demonstrably improves the demo |
| Large 7-inch HDMI / USB-touch display (Wisecoco labeling) | In hand; display and touch have worked; ASUS display also brought up | Main UI. Independently verify HDMI video, USB touch mapping, and stable power on final host |
| TP-Link powered USB hub | In hand and used | Peripheral connectivity, not a router. Use data ports for peripherals, not charge-only ports; verify supplied adapter and load |
| Raspberry Pi 4B, 4 GB | In hand; teammate is setting it up / reports setup complete | Intended standalone brain. Camera app, Linux capture backend, boot behavior, power/storage/network still need end-to-end acceptance |
| Arduino UNO Q, 4 GB / 32 GB eMMC | In hand; Linux-side USB/ADB detection and user-LED pulse verified | Physical shutter and selected sensor/control module. No working physical shutter or MCU sensor sketch claimed |
| ESP32-S3-BOX-3 | In hand; factory screen/touch, speaker and offline demo recognized by user | Future microphone/speaker endpoint. Host adapter is experimental; no live voice-to-camera or ElevenLabs playback integration verified |
| ASUS Ascent GX10 | In hand; latest session reports SSH login, NVIDIA GB10, internet and Python verified | Optional external AI worker; application/model deployment and camera integration remain unfinished |
| ESP32-S3-DevKitC-1, N8R8 | In hand; backed up and flashed as UART-to-USB keyboard/mouse utility; Mac native USB enumeration verified | Setup/debug utility, not the camera brain or BOX-3. ASUS HID delivery was not proven; omit from enclosure unless a real product need emerges |
| Nordic nRF52840 development kit | In hand from photos; no application test | Spare; no MVP dependency |
| Arducam B0033 5 MP camera | Previously identified in hand; untested | Optional alternative. Confirm exact sensor, ribbon/connector, mounting and software before replacing Logitech |
| MLX90640-D110 thermal module | Previously identified in hand; untested | Optional sensor mode. Verify voltage/bus and real readings; optical registration is a separate task |
| Additional Arduino sensors | User reports receipt; exact inventory not reconciled | Photograph model labels and count cables before assigning interfaces or CAD positions |

### Requested, discussed, or modeled is not the same as received

The earlier reservation wish list included a Pi 5 kit, official power supply, Grove Beginner Kit, microSD and reader, foam board, Velcro, gaffer tape, touchscreen accessories, printer and accessories, and a speakerphone. Do not treat those requests as confirmed checkout. The working Pi being discussed now is a Pi 4, not a verified Pi 5.

Still reconcile: exact 8×8 item, Grove kit, pushbutton/control module, female-to-female jumpers, breadboard, mounting materials, Pi supply/storage/cooling, display adapters, printer package, and standalone speakerphone. The current CAD concept also depicts an HQ camera/manual lens, depth module, IMU, environmental/proximity modules, and speakerphone; the model alone is not evidence those items are in hand.

## 4. Modular architecture

```text
Logitech USB camera ──────────┐
Large display: HDMI video ◄──┤
Large display: USB touch ───►│  CAMERA HOST: Pi target / Mac development
UNO Q control + sensors ────►│  preview • capture • originals • gallery • UI
                            │  orchestration • provider adapters • health
BOX-3 mic / speaker ◄───────►│
                            └── network ──► cloud AI / ElevenLabs
                                         └► optional ASUS AI worker

Powered USB hub: data/power distribution where appropriate, not networking.
ASUS remains external and ventilated. ESP HID bridge is a setup tool only.
```

### Module contracts

| Module | Boundary | Implementation rule |
|---|---|---|
| Camera acquisition | Fresh frames + health; captured original artifact | Hide Mac AVFoundation versus Linux capture behind one interface. Select the intended device explicitly |
| UI/display | Browser UI, touch input, preview and result states | Large display is primary control surface. Touch USB is separate from HDMI video |
| Capture controller | A single capture action used by screen and hardware input | Serialize/debounce inputs and return success/failure; physical input must not bypass capture validation |
| UNO Q adapter | Proposed button events and typed sensor readings | Choose and document actual transport/firmware after pin and voltage checks. Existing ADB LED link is not this implementation |
| Sensor state | Named readings, units, timestamp and freshness | Freeze real values at capture; missing/stale values stay absent, never invented |
| Image editing | Original + prompt/preset → separate output + provenance | Distinguish local effects, manual Codex-assisted edits, and automated provider edits. Preserve original and handle timeouts |
| Voice endpoint | Proposed push-to-talk audio in; generated audio out | BOX-3 requires an audio transport/firmware path; it is not assumed to be a generic USB speaker |
| ASUS worker | Proposed authenticated job API with health/timeout | Optional offload. No dependence on direct USB/HDMI links to Mac; failure falls back to camera-only flow |
| Storage/export | Capture ID, original, edit history and metadata | No credentials in artifacts; no automatic public upload of photos |

Existing local software exposes status/frame/gallery and capture/render/speech/sensor routes. Treat them as the current implementation to evolve, not a network-ready remote API: it currently uses localhost and request guards. Do not simply expose it to venue Wi-Fi. Add deliberate authentication, bounded requests, and protected deployment before remote access.

### Power and wiring boundaries

- Use the correct matched supplies for Pi, ASUS, display and powered hub. Confirm actual ratings and total USB load before assembly; connector fit is not proof of sufficient power.
- Route USB data, HDMI and power as separate labeled paths. Leave strain relief and service loops.
- Do not connect GPIO merely from a conceptual diagram. Confirm each board/module's pinout, logic voltage, grounding, pull-ups and bus address first; add level shifting where required.
- Keep exposed PCB undersides insulated and on standoffs. Do not use bare foam/adhesive as the only electrical protection or block ventilation.
- No battery integration in the baseline. Bench-powered operation is acceptable for the MVP.

## 5. What is integrated versus unfinished

### Working or specifically demonstrated

- Mac-hosted local camera preview, explicit capture, original files, local effects, gallery/download flow.
- Large-screen display/touch operation has been exercised; final-host mapping still needs verification.
- UNO Q Linux-side detection and a reversible user-LED pulse; not physical shutter input.
- BOX-3's factory display/touch/speaker demo; not custom application audio.
- ESP HID utility backup, flash verification and serial protocol; native USB device enumeration on Mac.
- ASUS remote access and basic compute/network checks in the latest session; not AI service deployment.

### Code exists, but end-to-end acceptance is still required

- Generative image-edit and ElevenLabs hooks exist in the local server; configured credentials, real provider calls and final output path must be verified. User preference is Codex-assisted image editing initially, with provider replacement later. Manual editing is not an automated in-app feature.
- Experimental BOX-3 serial observer/parser has synthetic tests. No real recognized-command event has triggered capture successfully.
- Sensor ingestion and snapshot logic exist, but the physical sensor transport and actual sensor values are not proven.

### Not yet accepted on Aditya's hardware integration track

- Linux camera backend and complete deployment on Pi; current capture implementation is Mac AVFoundation-specific.
- Physical shutter wiring/firmware, debounce and event bridge.
- Full voice loop: microphone capture, speech interpretation, camera action, ElevenLabs generation and BOX-3 playback.
- ASUS job service/model installation and authenticated connection to camera host.
- Measured, fabrication-ready CAD and integrated power/cable assembly.
- Printer integration, intentionally deferred.

## 6. Mechanical / CAD modularization

There is an existing **Tesseract** concept under `design/tesseract/`: nested-cube tabletop installation, approximately 320 mm outer width, 176 mm inner cube, top rail around 345 mm. These are concept dimensions, not validated fabrication geometry. Do not silently redesign or manufacture it from approximate component envelopes.

Build removable subassemblies:

1. **Camera pod:** baseline Logitech mount with unobstructed lens and cable exit; replaceable faceplate for a future camera. No motorized focus mechanism assumed.
2. **Screen module:** supported bezel/ledge, accessible HDMI, USB touch and power connectors; protect the panel without obstructing touch.
3. **Control module:** one shutter and optional mode control, UNO Q on standoffs, labeled disconnectable harness. Add only verified sensors.
4. **Compute tray:** removable Pi with cooling, storage and connector access. Prototype on Mac externally until Pi passes; do not make Mac part of permanent enclosure.
5. **Voice module:** removable BOX-3 cradle with microphone/speaker openings unobstructed. Speakerphone dock is an alternative only if received and tested, not an additional requirement.
6. **Power/cable tray:** accessible hub, labeled cables, strain relief, ventilation, service loops and separate supply routing.
7. **Optional sensor rail:** swappable brackets; thermal/depth optics need measured view alignment and calibration, not just adjacent mounting.

ASUS stays outside the camera body. Spare Nordic and HID boards do not need CAD space. Use foam-board/Velcro mockups if materials are actually available; retain easy removal. Only create final holes, connector cutouts and joints after measuring real parts and plug bend radii. Environmental sensors need separation from compute heat and screen light. A concept render is not supplier CAD or a safety-tested enclosure.

## 7. Team work that can happen in parallel

Ownership below is suggested; assign names at the next team check-in.

| Workstream | Owner suggestion | Independent task now | Handoff artifact |
|---|---|---|---|
| Pi platform | Teammate already setting up Pi | Confirm OS, power, storage, network and remote access; test USB camera + HDMI + touch | Setup notes, device identities, repeatable boot/test result; share credentials privately |
| Mechanical/CAD | CAD teammate | Measure received parts; make removable camera/screen/control trays and cable plan | Dimensions, photos, fit checklist, editable CAD; mark assumptions |
| Controls/sensors | Electronics teammate | Inventory exact boards, buttons, jumpers; choose one safe shutter circuit | Pin/voltage table, harness labels, debounce/event specification |
| App/integration | Aditya + software agent | Preserve Mac baseline; port camera backend; unify capture inputs and provider adapters | Reproducible run instructions, tests, module health and failure states |
| Voice | Firmware/audio teammate | Establish BOX-3 custom audio transport separately from factory demo | Recorded audio sample and known playback test before camera integration |
| Experience/demo | Product/UI teammate | Define 2–3 high-impact edit presets and original/result comparison flow | Short demo script, example inputs/outputs, clear AI consent/error copy |
| Optional compute | Available teammate/agent after core work | Prepare ASUS worker without blocking Pi/camera | Health endpoint and one reproducible offload job |

Do not have two people flash the same board or own the same serial port simultaneously. Each module should have one hardware owner, explicit test evidence, and a handoff before integration. Keep secrets out of GitHub and team screenshots.

## 8. Integration sequence and acceptance gates

1. **Freeze the baseline:** run Mac photo loop; record camera, screen orientation and known-good cabling. Keep a rollback path.
2. **Pi proof:** teammate brings up Pi; port Linux camera acquisition and run the exact same UI/capture flow. Test real touch, stable preview, save/reopen, reboot and peripheral reconnect. Until passed, call it a target, not integrated.
3. **One physical shutter:** breadboard or verified button module first; test one press/one capture, rapid presses, held press and board unplug. UI capture must remain available.
4. **Mechanical mockup:** fit real camera, display, Pi and control module; validate cable reach, connector access, stability and cooling before closing panels.
5. **AI proof:** process one explicit capture through the chosen editing path; show original and generated result, duration, failure and retry. If manual Codex editing is used, label it as manual assisted demo flow.
6. **Voice output first:** generate a short ElevenLabs response and play it through a verified endpoint. Then add push-to-talk input; avoid open-ended always-listening behavior as the first milestone.
7. **Optional sensor/ASUS additions:** add one feature at a time with observable health and a clean disable/fallback. No fake sensor values or silent AI success.
8. **Demo rehearsal:** perform at least ten capture cycles, including network loss/provider failure, reconnect and cold boot; original photos must remain accessible throughout.

## 9. Immediate next steps / blockers

- Obtain the Pi teammate's actual acceptance results and privately supplied access; a working OS is not proof the camera application is ported.
- Reconcile the sensor/cable/material inventory with labeled photos. We do not need more random sensors to start the core camera.
- Pick the single physical shutter control and verify its wiring; exact missing jumpers/button cannot be inferred from reservations.
- Measure camera/display/compute/connectors for CAD. The existing concept contains additional unverified components.
- Select the initial AI demonstration path and separately prove the automatic integration. Do not conflate a local enhance button with generative editing.
- Establish the BOX-3 audio path; factory speaker success does not establish ElevenLabs compatibility end-to-end.
- Keep ASUS optional. Remote access is now available, but model/application preparation must not stall the standalone photo loop.

**Team definition of done:** a stable, serviceable physical camera with fresh preview, deliberate capture, preserved originals, clear enhancement choices and graceful failures; every claimed hardware/AI/voice capability has a repeatable live test. Optional modules can be added or removed without rebuilding the core camera.

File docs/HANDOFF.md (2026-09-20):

# Nimbus — handoff, 20 Sep 2026, 01:10 ET

Written for whoever picks this up next: a teammate, or a fresh agent session. It says what exists, what is
running where, what is still open, and how to get in. Design and rationale live in [DESIGN.md](DESIGN.md);
this is the state of the world.

## The product in one line

**A camera that photographs the air.** The person stays exactly as shot — checked pixel by pixel and printed
on the card — and the surroundings are rendered from what the camera measured. You talk to it, and it
answers, searches its own photos, posts to Instagram, and puts a photo on your phone with a QR code.

## What is running right now (updated 21:20 ET)

| Machine | Role | Address | State |
|---|---|---|---|
| **Pi 4** (`raspi4`) | the camera: sensors, screen, touch, voice | hotspot 172.20.10.11 (venue 10.189.57.130) · tailnet 100.72.177.61 | Nimbus on the panel, two-mode build; starts at boot with keys from `/etc/nimbus.env` |
| **ASUS GB10** (`gx10-5493`) | the GPU: ComfyUI + Nimbus API :8000 + Elasticsearch :9200 | hotspot 172.20.10.12 (venue 10.189.73.14) · tailnet 100.90.82.31 | all three up; `@reboot` crontab brings them back (no sudo there, so no systemd) |
| **Windows box** | old GPU, fallback only | ZeroTier · `nimbus.akvaithi.page` | up, unused |
| **MacBook** | development | venue 10.189.81.118 | repo, Keychain, the ElevenLabs agent |

All on **HackMIT.2026** wi-fi; the Pi reaches the ASUS on the venue address (the tailnet ACL only opens 22).

**Deployed and verified end to end from the Pi:** Nimbus and Souvenir both render on the GB10, subject
verified, Muse tags the photo, Elasticsearch on the ASUS indexes it, and search finds it. The Pi has rebooted
once and came back into Nimbus on its own.

Machine-side scripts: `~/start_nimbus.sh` on the Pi (restart the camera), `~/restart_api.sh` and
`~/start_all.sh` on the ASUS (restart the API; boot everything).

## Buttons — reflashed, one pin named

The UNO Q now runs **our sketch** (`device/unoq/nimbus_unoq.ino`): thermal frames as before (commands `0x01`,
`0x02`) plus **`0x07` → buttons** (held mask + pressed-since-last-read mask, bit n = digital pin Dn, all of
D2–D13 pulled up). Flashed from the board's own Linux over ADB from the Pi; how-to in `device/README.md`.

The Pi reads it (`hw.I2CButtons`, on with `NIMBUS_I2C_BUTTONS=1`) and knows **only `shutter=4`** so far.
**Arun has not pressed the buttons yet.** When he does, the log names the other three
(`[buttons] unnamed pin D9 pressed`); put them in `NIMBUS_BUTTONS="shutter=4,mode=…,talk=…,browse=…"` in
`~/start_nimbus.sh` and `~/.config/labwc/autostart` on the Pi and run `~/start_nimbus.sh`.

Two findings from the reflash: the Zephyr core's `Wire` cannot do a repeated start (the MLX90640 driver
is patched, `device/unoq/patches/`), and the array delivers one chess subpage per read, so ~half the pixels
are live at any moment — plenty for temperature and motion. The thermal array is on **Wire2 (A4/A5)** and the
Pi is on the header SDA/SCL (`Wire`); the sketch finds both itself.

## Look

Brand palette (sky `#70C8FB`, pink `#FF9EC6`, lime `#E2F542`, slate `#1B3139`, coral `#FF7B9C`) and Plus
Jakarta Sans (bundled, OFL, `pipeline/nimbus/data/fonts`) on the panel and on the print. **The AI Camera print
is square** (photo fitted whole, headline + subtitle, no sensor line) — the same file prints, posts and shows.
The QR card (`card.jpg`) still carries the readings for the phone.

## The two modes (changed 23:50 ET)

**AI Camera** = the pipeline's Souvenir dial with a **fifty-format menu** (`sense.KINDS`: cave painting, alien abduction report, medieval wanted poster … barbie doll packaging). Muse picks the format from the scene (`tagger.souvenir`), the GB10 paints it around the untouched subject. Verified: a Red Bull → "energy drink can", lightning. Now on **klein 9B** (`gb10-9b`) at **1.0 MP** (~11 s a render; 4B is the `gb10` fallback). Capture is two-phase: **~16.5 s end to end** from the shutter. Landscape (portrait was tried: `NIMBUS_ROTATE=90/270`). **Visa Buy** = the shutter saves the frame as shot (no segmentation, no diffusion, no server) and goes straight to identify → offers → BUY WITH VISA. The old "Nimbus" air mode is no longer on the dial (still in the API).

## Shop (Visa)

Visa Buy shows the product's own picture beside the shot (Open Food Facts or an image search) and plays a
payment-terminal animation (card tap, contactless ripples, "Contacting Visa…") while the sandbox answers.

"What am I holding?" → `identify_product` (Muse vision → live search → offers) → "buy it" → `buy_it`. A
**SHOP** button is on the review screen. Checkout is a **real Visa Developer sandbox call** (Visa Direct pull-funds, MLE-encrypted, test card) —
verified approved from both the Mac and the Pi. Credentials: Keychain `visa-sandbox-user`/`-password`,
`/etc/nimbus.env` on the Pi, certs and MLE keys in `~/.nimbus/visa/` on both. Without them it falls back to
a simulated approval and the receipt says so. `python -m nimbus_cam.shop` is the self-check. Not yet run on
the rig by voice.

## What works, verified

- **Capture** end to end: Pi camera → ASUS GB10 → subject verified unaltered, ~32 s (klein at 2 MP, no upscaler).
- **The honesty guarantee**: the subject's pixels are identical to the frame as shot, checked in 8-bit inside
  the mask; every capture so far reports "subject unaltered · verified".
- **Sensors → picture**: temperature and motion from the MLX90640 over I2C (through the UNO Q), light from the
  camera frame, sound from the webcam mic, humidity/wind/cloud from Open-Meteo, labelled "(web)".
- **Screen**: 1024×600 panel, fullscreen, with touch buttons (mode · shutter · hold-to-talk · photos, and
  back/‹ ›/phone/post on a photo).
- **Audio**: mic = C270 webcam, speaker = **Whammo 2.0 Bluetooth speaker** (57:DB:A6:6E:87:96, paired and trusted; PipeWire default sink via `pipewire-alsa`), or the 3.5 mm jack. Tone out and 1 s in tested.
  **A speaker must be plugged into the jack to hear the camera.**
- **Voice**: ElevenLabs agent `agent_3501m2xfqx3yemcb5ph6tr8ekjen`, brain = Muse Spark via custom LLM, ten tools.
  Spoken to on the rig 20 Sep: "take a picture" → shot, described back through the speaker. Agent is now
  `agent_2901m2zkxyaped8sevtb87bx13b0` on a fresh ElevenLabs free account (10k characters — spend them on the demo).
- **Search**: Elasticsearch 8.15 on the ASUS (tarball, no docker), the camera indexes and searches it live.
- **Instagram**: posting as **@nimbus_hackmit2026**, token verified. **Every AI Camera photo auto-posts** (`NIMBUS_AUTO_POST=0` to stop): the picture alone, 1080² on a blurred pad, no card/QR, Muse's caption.
- **Souvenir**: Muse saw daisies, chose a seed packet, and produced "WILD DAISY MIX — sunshine you can plant".

## What's next (agreed 20 Sep, 01:00)

1. **More AI Camera testing** on the rig — different subjects and formats on klein 9B; watch for extra
   people and text; the camera is in portrait (`NIMBUS_ROTATE=270`).
2. **UI/UX polish** — the loading ring/progress bar is in; review screen, gallery flow and the shop screen
   need a pass with the touch panel in hand.
3. **Visa shopping experience** — the flow works (identify → offers → real sandbox approval); make it feel
   like shopping: product image, offer choice, a receipt screen worth photographing, voice confirmation.

## Not done

1. **Three button pins unnamed** (see above) — a one-line env change once Arun presses them.
2. **Sharing goes through the public server**: POST and the QR mirror the photo to `nimbus.akvaithi.page`
   (the Windows box) because Instagram cannot fetch from the hotspot; if that box is down, posting fails.
3. **Voice untested by voice** on the rig: the session connects and the devices are right, but nobody has held
   the button and spoken yet. A speaker must be in the Pi's 3.5 mm jack.
3. **The ASUS has no sudo for this user**, so ComfyUI, the API and Elasticsearch restart from a user `@reboot`
   crontab rather than systemd. Good enough for the event; check `~/start_all.sh` if something is missing after
   a reboot.
4. **The venue address of the ASUS is baked into the Pi** (`NIMBUS_API`, `NIMBUS_ES_URL` in
   `~/.config/labwc/autostart` and `~/start_nimbus.sh`). If DHCP moves it, update both.
5. **No printer** — dropped, HackMIT does not supply one.

## Secrets — rotate after the event

All of these were pasted into a chat transcript: the **Meta Model API key**, the **ElevenLabs key**, the
**Instagram token**, the **Tailscale auth key**, the **team SSH private key**, and the **Visa sandbox user
id, password and MLE private key**. They live in the MacBook's
Keychain (`meta-model-api-key`, `elevenlabs-api-key`, `ig-token`, `ig-user-id`) and, so the rig survives a
reboot, in **`/etc/nimbus.env` on the Pi** (root:raspi4, 0640 — the only copy outside the Keychain). Never in
the repo.

## Getting in

```bash
ssh pi                      # Pi, over the tailnet (~/.ssh/config alias)
ssh pi adb shell            # the UNO Q's Linux (user arduino), for reflashing
ssh -i ~/.ssh/hackmit_team_2026 asus@100.90.82.31
~/start_nimbus.sh           # on the Pi: restart the camera with keys and the right env
~/restart_api.sh            # on the ASUS: restart the GPU API
ssh pi 'XDG_RUNTIME_DIR=/run/user/1000 WAYLAND_DISPLAY=wayland-0 grim ~/screen.png'   # see the panel
```

The Mac is on a **separate tailnet profile**; `tailscale switch` returns to Arun's personal one.

## If it breaks

- **Panel black / no desktop**: something else holding the GPU. `sudo fuser -v /dev/dri/card1`. A kiosk
  experiment (`camera-kiosk`, `camera-stream`) used to hold it; both are disabled now.
- **Camera app dead**: `ssh pi '~/start_nimbus.sh'`, log at `~/nimbus-run.log`.
- **Captures fail**: check the ASUS API (`curl 10.189.73.14:8000/health`) — if the venue DHCP moved it, update
  `NIMBUS_API` in `~/start_nimbus.sh` and `~/.config/labwc/autostart` on the Pi.
- **Voice silent**: no speaker in the jack, or the agent id file is missing (`~/.nimbus/camera/agent.json`).

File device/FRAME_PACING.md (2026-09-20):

# Touchscreen frame pacing

The source defaults to a 15 FPS schedule; the tested Pi launcher selects SDL at
24 FPS. See [hardware results](FRAME_PACING_RESULTS.md). Other deployments can opt
into 24 or 30 FPS by setting `NIMBUS_UI_FPS=24` or `NIMBUS_UI_FPS=30` before
starting the camera process.  The only accepted values are 15, 24, and 30;
missing or invalid values use 15 FPS, and an invalid value emits one startup
warning.  Return to the baseline with `NIMBUS_UI_FPS=15` (or by unsetting the
variable).

The scheduler uses monotonic absolute deadlines.  When rendering or Tk is
slow, elapsed deadlines are skipped and the next callback is scheduled with a
positive Tk delay. When the next deadline has already passed, it drops overdue
slots and rebases with an 8 ms cooperative delay rather than waiting for another
full grid slot. This avoids a half-rate cliff under sustained overload. It does
not run a catch-up burst or add a timer/thread.
Animation timestamps remain the existing wall-clock values, so this change
does not alter the skin's animation equations or camera pipeline.

## Optional diagnostics

Set `NIMBUS_UI_FRAME_STATS=1` to print one aggregate report approximately every
10 seconds.  Reports contain the target FPS, completed Tk callback throughput,
render duration, Tk image/upload duration, label configure duration, total
callback p50/p95/max duration, missed scheduling deadlines, and render
failures.  Callback throughput is the rate at which this process completed Tk
callbacks; it is not a measurement of physical display presentation FPS.
Presentation timing requires later hardware instrumentation or observation.

Statistics retain only bounded duration samples and counters.  They never keep
rendered images.  The render duration includes any resize performed by
`Screen.render`, as well as skin rendering.  With diagnostics disabled there is
no per-frame timing or logging beyond the monotonic deadline calculation.

## Hardware test protocol

After integrating the cache and image-loading patches, use the same scene,
camera load, and interaction script for baseline 15 FPS, 24 FPS, and 30 FPS.
Record the aggregate reports and compare callback/render/upload/configure
tails, missed deadlines, and render failures.  For each setting, also record
sustained CPU use, temperature, and throttling; check touch and shutter
responsiveness; and inspect physical screen smoothness.  Repeat enough of each
run to expose warm-up and sustained-load behavior.  Unit tests make no throughput, smoothness, or thermal claim; the separate
results document records hardware measurements.

## Integration status

Pacing, cloud/fade caching, persistent Tk images, the optional SDL presenter and
capture-art prewarming are integrated. Background photo loading and experimental
camera-buffer changes are not included. The Pi was tested at 24 FPS; 30 FPS is
an available target, not an established sustained full-app result. Consult the
results document before interpreting a configured target as achieved throughput.

## Persistent Tk image

The screen now retains its Tk PhotoImage and updates its pixels with `paste`
when the frame dimensions are unchanged. It binds a new image only on first
presentation or a dimension change. A failed bind is retried on the next frame.
This removes per-frame Tk label reconfiguration without changing rendered pixels,
resolution, animation equations, or camera reads. Display update remains on the
Tk main thread. Diagnostics classify `paste` within image/upload time.

On the Pi, four RGB patterns read back from the actual Tk photo were byte-identical
after reuse. Headless integration tests cover reuse, changed dimensions, and
recovery after a failed label bind. See FRAME_PACING_RESULTS.md for the measured
benefit and remaining bottleneck; configured FPS is not delivered FPS.

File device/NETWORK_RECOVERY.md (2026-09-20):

# Pi ↔ ASUS network recovery

The camera failed with `No route to host` after switching hotspots because its
launcher retained the ASUS's old DHCP address. Both devices were online, but
on different hotspots. ASUS's API, Elasticsearch, and ComfyUI were healthy.
The existing Tailscale policy allows SSH; direct API port access timed out.

The Pi now connects to ASUS's stable Tailscale address through a dedicated SSH
tunnel. API and library traffic use loopback listeners on the Pi:

- `NIMBUS_API=http://127.0.0.1:18000` → ASUS `127.0.0.1:8000`.
- `NIMBUS_ES_URL=http://127.0.0.1:19200` → ASUS `127.0.0.1:9200`.

`ops/nimbus-asus-tunnel.service` is installed and enabled on the Pi. Keepalives
notice dead connections; systemd retries after five seconds. Both devices need
working network paths to their tailnet, but need not share Wi-Fi or a hotspot.
No firewall or tailnet ACL was widened, and no API listener was exposed by the
new configuration.

The dedicated Pi private key remains only at `~/.ssh/nimbus_asus_tunnel`.
ASUS's authorized public key restricts forwarding to the two service endpoints;
its options are `restrict,port-forwarding,permitopen="127.0.0.1:8000",permitopen="127.0.0.1:9200"`.
The Pi uses a separate known-hosts file copied from an already trusted ASUS host
key; strict host-key checking is enabled. No credentials are stored in this repo.

`~/start_nimbus.sh` exports the local endpoints after sourcing existing
credentials and waits briefly for API readiness. The graphical boot autostart
now invokes that same launcher, rather than duplicating stale DHCP addresses.
The wait is bounded; a prolonged network outage can still cause local-library
fallback and a capture error. This is automatic transport reconnection, not
transaction replay or offline AI generation. A capture in flight during an
outage may need to be retried once connectivity recovers.

## Verified on hardware

- Pi on Adi's hotspot, ASUS on Calvin's: API and Elasticsearch both HTTP 200.
- Terminated the tunnel's main process: systemd restarted it (`NRestarts=1`),
  and API readiness recovered to HTTP 200.
- Camera restarted using Elasticsearch over the tunnel.
- Real AI capture over separate hotspots: shutter release at 20.328 seconds,
  photo review at 43.833 seconds (23.505 seconds end to end), with
  `AI Camera · subject unaltered · verified` in the camera log. Automatic
  posting was disabled. This run did not substitute a local/fake capture.

Reboot and a full physical Wi-Fi outage have not been tested.

## Rollback

Backups on Pi are under `~/frame-pacing-test-20260920/`:
`start-before-network.sh` and `autostart-before-network`. Restore those only if
the previous network endpoint is reachable. Disable the tunnel with
`sudo systemctl disable --now nimbus-asus-tunnel`. Remove only the dedicated
`nimbus-pi-api-tunnel` authorized-key entry on ASUS if decommissioning it.

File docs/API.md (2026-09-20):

# Nimbus pipeline API

The image-processing service the camera frontend calls. It runs on the MacBook at the table:

```bash
cd pipeline && uv run uvicorn nimbus.api:app --host 0.0.0.0 --port 8000
```

- Base URL: `http://<mac-ip>:8000` locally, or `https://nimbus.akvaithi.page` (the copy running on the GPU box, used by the public demo).
- Interactive docs: `http://<mac-ip>:8000/docs`.
- CORS is open.
- Every image upload is `multipart/form-data`.
- Every image response is raw `image/jpeg` (or `image/png` when you send `format=png`), with metadata in headers.

## Concepts

| Thing | What it is |
|---|---|
| **Look** | A reusable recipe stolen from a reference photo: a color grade (3D LUT), measured traits, grain and vignette, user sliders, and a plain-language explanation. |
| **Brush** | A texture captured from the real world, made seamless, used for World Brush painting. |
| **Tier 0** | Faithful and fast (under 1 s, no GPU). The default for everything. |
| **Tier 1** | "Reimagine": FLUX.2 klein restyles the photo on the GPU box (about 10–15 s measured, end to end). Creative, not faithful. Falls back to tier 0 automatically. |
| **Style** | A built-in mode-dial setting. Families: `grade` (LUT only), `camera` (grade + procedural optics, sensor and print artifacts, e.g. 2006 digicam or instant print), `reimagine` (diffusion repaint, e.g. anime painting, watercolor, toy diorama, followed by ESRGAN upscaling to sensor resolution). |

## The camera flow → endpoints

| User does | Call |
|---|---|
| Shares an Instagram post to the camera | `POST /looks` with `image` (and `before` if the post is a before/after pair) |
| Browses saved looks | `GET /looks` |
| Turns the mode dial | `GET /styles` once; grey out entries with `available: false` |
| Shoots in a built-in style | `POST /stylize` |
| Viewfinder with a look selected | `POST /preview` per frame (tens of ms) |
| Presses the shutter | `POST /render` |
| World Brush: holds the button for 3 s on a texture | `POST /brushes` with the viewfinder frame |
| Draws on the photo with the brush | `POST /brushes/{id}/paint` with the photo and a stroke mask |
| Confirm → print / upload | Use the image returned by `/render` or `/paint` |

## Endpoints

### `GET /health`

```json
{"ok": true, "tier0": true, "tier1": true,
 "diffusion_backends": [{"url": "http://172.25.242.235:8188", "ok": true, "reason": "ok", ...}],
 "vision": {"model": "gemma3:4b", "reachable": true}, "looks": 3, "brushes": 1}
```

Use `tier1` to decide whether to show the "Reimagine" button.

### `POST /looks` — create a Look

| Field | Type | Notes |
|---|---|---|
| `image` | file, required | The styled photo (the Instagram post). |
| `before` | file, optional | The unedited original, if the post shows a before/after. Makes the grade essentially exact. |
| `source` | `upload` \| `instagram` \| `world` | Default `upload`. |
| `name` | string, optional | Otherwise the vision model names it. |
| `analyze_look` | bool | Default `true`. |

Returns the Look (below) in about 1 s. `analysis.source` is `"measured"` at first. A few seconds later a background vision pass replaces it with `"vision"`, including a better `name`. Poll `GET /looks/{id}` if you want to show the explanation.

```json
{
  "id": "3f9c2a1b7d4e",
  "name": "Faded Coastal Film",
  "source": "instagram",
  "method": "neutral_fit",
  "recommended_strength": 0.5,
  "measured": {"black_point": 11.2, "white_point": 93.1, "contrast": 19.4, "saturation": 14.8,
               "warmth": 9.1, "tint": 1.2, "shadow_tint_ab": [-4.1, -6.0],
               "highlight_tint_ab": [3.2, 12.5], "grain": 0.21, "vignette": 0.14, "mean_lightness": 52.3},
  "analysis": {
    "name": "Faded Coastal Film", "summary": "...", "mood": ["nostalgic", "airy", "calm"],
    "lighting": "...", "film_stock_guess": "Kodak Portra 400",
    "why_it_looks_this_way": ["Blacks are lifted to L*=11, so shadows read as matte", "..."],
    "how_to_shoot_it": ["..."], "restyle_prompt": "...", "source": "vision"
  },
  "effects": {"grain": 0.21, "grain_size": 1.0, "vignette": 0.14},
  "adjustments": {"warmth": 0, "tint": 0, "saturation": 0, "contrast": 0, "exposure": 0, "fade": 0}
}
```

- **`method`**: `pair` (you sent `before`), `neutral_fit` (estimated), or `neutral_diffusion` (after `/refine`).
- **`recommended_strength`**: the default strength for tier 0. It is `1.0` for pair Looks, `0.5` for estimated ones and `0.25` after `/refine` (see `docs/EVAL.md` for why). Put it on a slider.
- **`why_it_looks_this_way`** and **`how_to_shoot_it`**: the "explain this look" content.

### `GET /looks` · `GET /looks/{id}` · `DELETE /looks/{id}`

### `PATCH /looks/{id}` — edit name and sliders

```json
{"name": "Mine", "adjustments": {"warmth": 0.3, "saturation": -0.2}, "effects": {"grain": 0.4, "grain_size": 1.0, "vignette": 0.2}}
```

Adjustment ranges:

| Slider | Range |
|---|---|
| `warmth`, `tint`, `saturation`, `contrast` | −1 to 1 |
| `exposure` | stops |
| `fade` | 0 to 1 |

Unknown keys return 400.

### `GET /looks/{id}/lut.cube` · `GET /looks/{id}/ref.jpg`

The `.cube` opens in Lightroom, Premiere, DaVinci Resolve and ffmpeg (`-vf lut3d=file.cube`).

### `POST /looks/{id}/refine`

Re-estimates the grade with the diffusion neutralizer, the best blind method in the eval. It takes about 9 s and needs `tier1`. Returns 503 when no GPU is available.

### `POST /preview` — viewfinder

| Field | Default |
|---|---|
| `frame` (file) | required |
| `look_id` | required |
| `strength` | `1.0` |
| `max_side` | `720` |
| `format` | `jpeg` |

Color only (no grain or vignette). About 10 ms of processing at 540p, plus upload and encode. If the frontend can run it locally, it can instead fetch `lut.cube` once and apply it with a WebGL 3D texture.

### `POST /render` — final photo

| Field | Default | Notes |
|---|---|---|
| `photo` | required | Full-resolution capture. |
| `look_id` | required | |
| `tier` | `0` | `0` faithful · `1` reimagine |
| `strength` | the Look's `recommended_strength` (tier 0), `1.0` (tier 1) | 0–1 |
| `max_side` | none (full size) | Long side of the result. The public demo asks for 1100 so a render round-trips in under a second. |
| `quality` | `92` | JPEG quality, 40–98. |
| `scene_cct` | none | Ambient color temperature in kelvin from the light sensor. The photo is white-balanced to daylight before the Look is applied, so Looks render consistently under any lighting. |
| `mode` | `detail` | Tier 1 only: `detail` (diffusion color and light, the photo's own fine detail), `lut` (diffusion distilled into a global grade), `raw` |
| `protect_skin` | `0.5` | Tier 0: how much to hold skin tones back from the grade |
| `seed` | `1` | Grain and diffusion seed |
| `format` | `jpeg` | |

Response headers:

| Header | Meaning |
|---|---|
| `X-Tier-Used` | `0` or `1`. It can be `0` even when you asked for `1`. |
| `X-Fallback-Reason` | Why tier 1 was skipped, e.g. `GPU busy: Ollama has gemma4 loaded`. |
| `X-Mode-Used` | Tier 1 mode actually used. |
| `X-Alignment` | Tier 1: 0–1, how well the diffusion output kept the composition. |
| `X-Timings` | JSON, seconds. |

### `GET /styles`

```json
[{"id": "anime", "name": "Anime Painting", "family": "reimagine",
  "description": "Hand-painted anime background art in the style of Studio Ghibli films.",
  "needs_gpu": true, "available": true}, ...]
```

| Family | Styles | Needs GPU |
|---|---|---|
| `grade` | `velvia`, `portra`, `teal_orange`, `faded_matte`, `mono` | no |
| `camera` | `digicam`, `cinestill`, `instant`, `miniature`, `pixel` | no |
| `reimagine` | `anime`, `watercolor`, `poster`, `golden_hour`, `diorama` | yes |

### `POST /stylize`

| Field | Default | Notes |
|---|---|---|
| `photo` | required | Resized to a 12 MP sensor capture if larger. |
| `style_id` | required | From `GET /styles`. |
| `seed` | `1` | Diffusion, grain and noise seed. Change it for a different take. |
| `preserve_faces` | `0.7` for reimagine styles | 0–1. Detects faces and blends the photo's own facial structure back into the diffusion result. 0 disables it. |
| `scene_cct` | none | Light-sensor color temperature (K); white-balances before styling. |
| `max_side` | none (full 12 MP) | Long side of the result. Use about 1600 for a quick on-camera preview. |
| `format` | `jpeg` | |

Measured timings for a 12 MP capture rendered at 3000 px:

| Family | Time |
|---|---|
| `grade` | ~0.3 s |
| `camera` | 0.05–1 s |
| `reimagine` | ~20–25 s (1 MP diffusion + ESRGAN on the box, plus transfer) |

`instant` returns a square image in its print border, ready for the printer.

Responses carry `X-Style` and `X-Timings`. A GPU style with the box unavailable returns **503** at once, with the reason in `detail`. A failed GPU job returns **502**.

### `WS /ws/preview` — live viewfinder

Open the socket, send `{"type":"style","style_id":"anime","denoise":0.45,"still_blend":true}`, then push
JPEG frames as binary messages (640×360 is plenty; send the next one after the previous reply).

Each processed frame comes back as a JSON line followed by its JPEG:

```json
{"type":"frame","style":"anime","local_ms":63,"motion":0.031,"alignment":0.72,
 "hero_mix":0.0,"distilled":true,"bytes":27310,
 "diffusion":{"gpu_ms":229,"round_trip_ms":270,"queue_ms":3,"dropped":0,"frames":41}}
```

For GPU styles a second pair follows whenever a new diffusion frame lands: `{"type":"hero",...}` and the
raw 256 px diffusion JPEG, for an inset.

| Field | Meaning |
|---|---|
| `local_ms` | Time spent on this Mac for that frame |
| `diffusion` | Present only on frames where a new GPU frame landed |
| `motion` | Frame-to-frame difference; under 0.012 counts as holding still |
| `hero_mix` | How much of the diffusion frame is blended in (rises to 0.85 after ~0.6 s still) |
| `alignment` | Layout match between the camera frame and the diffusion frame (0–1) |
| `distilled` | The local preview is using colors fitted from a diffusion frame |

Measured (Mac → GPU box over ZeroTier): local layer **14–16 fps**, diffusion **3.8 fps** at 256 px with a
**270–400 ms** round trip. Grade and camera styles never touch the network. `GET /viewfinder` serves a
browser page that drives all of this from a webcam.

### `POST /brushes` — lock in a texture

| Field | Default | Notes |
|---|---|---|
| `frame` | required | The viewfinder frame. |
| `crop` | `true` | Samples the center 35% square. Send `false` with a pre-cropped patch. |

Returns `{"id", "material", "description", "paint_prompt", "mean_rgb"}`. `material` starts as `"captured texture"`; the vision model names it (e.g. `"weathered brick"`) a few seconds later.

### `GET /brushes` · `GET /brushes/{id}` · `GET /brushes/{id}/tile.png` · `GET /brushes/{id}/patch.png`

`tile.png` is the seamless version. Use it as a CSS or canvas pattern to preview strokes live on the client.

### `POST /brushes/{id}/paint`

| Field | Default | Notes |
|---|---|---|
| `photo` | required | |
| `mask` | required | PNG, white = paint. Any size; it is resized to the photo. Draw strokes with a soft round brush on a black canvas. |
| `mode` | `fast` | `fast` (tiled texture lit by the photo's own shading, under 1 s) · `ai` (FLUX.2 klein inpaint that wraps and relights the material, ~11 s measured) · `auto` (`ai` if the GPU is free, else `fast`) |
| `scale` | `1.0` | Tile size; 1 = a quarter of the photo's short side. |
| `opacity` | `1.0` | |
| `seed` | `1` | |
| `format` | `jpeg` | |

Returns the painted image with `X-Mode-Used` and `X-Fallback-Reason`.

## Errors

JSON `{"detail": "..."}` with these statuses:

| Status | Meaning |
|---|---|
| 400 | Bad image, empty mask, or unknown slider |
| 404 | Unknown look or brush |
| 502 | GPU job failed (`/refine` only) |
| 503 | No GPU (`/refine` only) |

Render and paint never fail over GPU trouble; they degrade to tier 0 or `fast`.

**Public instance limits** (`https://nimbus.akvaithi.page`): 3 concurrent live-preview sockets, 20 GPU calls and
12 new Looks per minute per address, and only the newest 300 Looks are kept on disk. All are environment
variables (`NIMBUS_MAX_SESSIONS`, `NIMBUS_GPU_CALLS_PER_MIN`, `NIMBUS_LOOKS_PER_MIN`, `NIMBUS_MAX_LOOKS`).

## Example

```bash
BASE=http://localhost:8000
LOOK=$(curl -s -F image=@insta_post.jpg -F source=instagram $BASE/looks | jq -r .id)
curl -s -F photo=@capture.jpg -F look_id=$LOOK -F scene_cct=4300 $BASE/render -o out.jpg -D -
BRUSH=$(curl -s -F frame=@brick_wall.jpg $BASE/brushes | jq -r .id)
curl -s -F photo=@capture.jpg -F mask=@strokes.png -F mode=auto $BASE/brushes/$BRUSH/paint -o painted.jpg
```

## Capture (the shutter)

Design and rationale: [DESIGN.md](DESIGN.md).

`POST /capture` — multipart: `photo` (file), `readings` (JSON string), `dial` (0 Nimbus, 1 Souvenir),
`seed`, and `souvenir` (JSON) on dial 1. `readings` takes any subset of `temp_c`, `rh` (%), `lux`, `db`, `pm25` (µg/m³),
`pressure_hpa`, `wind` (m/s), `cloud` (%), `cct` (K). Humidity, temperature, wind and cloud are filled from the local
weather when no sensor reports them, and listed in `web`. The subject's pixels are never changed. With no GPU
the capture falls back to the sensor effects alone (`dial_used`, `fallback_reason`).

`POST /captures/publish` — for shots the camera rendered on its own board (the no-GPU fallback): multipart `meta` (JSON from
`capture.meta_for`), `photo`, `as_shot`, `mask` (JPEGs from `capture.render_files`). The server assigns the
id, draws the card (its QR code needs the id) and marks `processed_on: "camera"`.

Both return the capture's metadata: `id`, `dial_used`, `untouched`, `proof`, `readings`, `web`, `processed_on`,
`timings`. Images:

| GET | What |
|---|---|
| `/captures/{id}/card.jpg` | shareable card (photo, readings, proof, QR code); this is what gets posted |
| `/captures/{id}/photo.jpg` | the finished photograph |
| `/captures/{id}/as_shot.jpg` | the input, for the before/after slider |
| `/captures/{id}/mask.jpg` | what the AI was allowed to touch, tinted |
| `/captures` | newest-first list for the gallery |
| `/c/{id}` | short link on the card's QR code → the gallery page for that capture |

## Printing

Off unless the server is started with `NIMBUS_PRINTER=<CUPS queue>` (the GPU box uses `Epson_XP4200`, an XP-4200 on
USB via `ipp-usb`). Optional: `NIMBUS_PRINT_TOKEN` (callers must send it as `X-Print-Token`) and
`NIMBUS_PRINTS_PER_MIN` (default 6 per client address).

`POST /captures/{id}/print` — query parameters, all optional. **A photo prints as one polaroid filling a 3x4 in page
edge to edge, whatever else the caller sends** (an older camera asking for `size=4x6` gets the same); a `card`
prints as it is on 4x6. `which` (`photo` default, or `card`); `layout` picks something else by name:
`polaroid1full` (the default for a photo), `polaroid1` (one polaroid centred on a 3x4 page with a white margin),
`polaroid4` (four to a 4x6 sheet, only when asked for) or `single` (the picture as it is); `size`
(`3.5x5 4x6 5x7 8x10 A4 A6 Letter Legal`) and `borderless` for `layout=single`; `media_type` (`Photographic`,
`PhotographicGlossy`, `PhotographicHighGloss`, `PhotographicSemiGloss`, `PhotographicMatte`, `Stationery`,
`StationeryCoated`; omit for `NIMBUS_PRINT_MEDIA`, else the printer's own setting); `scaling` (`fit` or `fill`, for
`single`); `quality` (`draft` is the quickest, `normal`, `high`; default `draft`, or `NIMBUS_PRINT_QUALITY`, or
`printer` there for the printer's own setting); `copies` (1-10, each sent as its own job because the XP-4200
ignores `copies`). Returns once CUPS has the job:
`{"capture", "which", "queue", "job", "jobs", "size", "borderless", "media_type", "scaling", "copies", "layout",
"quality"}`. Errors: 400 bad option, 401 wrong token, 404 no such capture, 429 too many prints, 502 CUPS refused the
job, 503 printing is not enabled here or CUPS is unavailable.

`GET /printer` — `{"enabled": false, …}`, or the queue's `state` (`idle` / `printing`) and `ready`. Never prints.

The camera's `NIMBUS_API` must point at the server that owns the printer. `NIMBUS_PRINT_LAYOUT`, `NIMBUS_PRINT_SIZE`,
`NIMBUS_PRINT_QUALITY`, `NIMBUS_PRINT_MEDIA` and `NIMBUS_PRINT_TOKEN` set what the camera sends.

The frames are fixed templates (`nimbus/data/polaroid_frame*.png`, built once by
`scripts/build_polaroid_template.py`); nothing is generated per print. The Nimbus and HackMIT logos are one shape
(`polaroid_logo*.png`) filled with the photo's most prominent colour. `nimbus/print_dev.py` is a localhost dev page
with Print, Print lines (a cutting guide), copies and speed.

## Two-phase capture

`POST /capture/prepare` (photo, readings) → `{"prepared": id}`; the subject mask is computed in the background.
`POST /capture/finish` (prepared, dial, seed, souvenir) → the same `CaptureMeta` as `/capture`, stored under that
id. Prepared frames expire after three minutes. The camera uses this so the upload and segmentation overlap the
~6 s Muse takes to choose the format.

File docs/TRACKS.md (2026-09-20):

# Sponsor tracks — the write-up, and what to show a judge

## Sponsor Track Write-Ups

**LongLake - Convince a non believer ✅**
The non-believer is the photographer who says AI ruins photos. Nimbus never touches the subject: the person or object is segmented (ISNet ∪ U²-Net human), only the surroundings are re-rendered, and the original pixels are composited back bit-for-bit with a 2 px edge blend. Every capture is then verified in 8-bit inside the eroded mask and the result is printed on the card: "subject unaltered · verified". The proof is measured, not asserted, and a test suite asserts it for every mode and every sensor extreme.

**Asus - Use Asus Hardware ✅**
The ASUS GX10 F470 (GB10, 128 GB unified memory) runs ComfyUI with FLUX.2 klein 9B (bf16 + fp4 8B text encoder) doing masked inpainting at 1.5 MP in ~19 s, the Nimbus API and Elasticsearch 8.15 — one box, no cloud image processing. klein 4B (~9 s) is the fast fallback profile. An A/B on the same photo: 4B kept the room and pasted in a stranger; 9B built the scene.
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

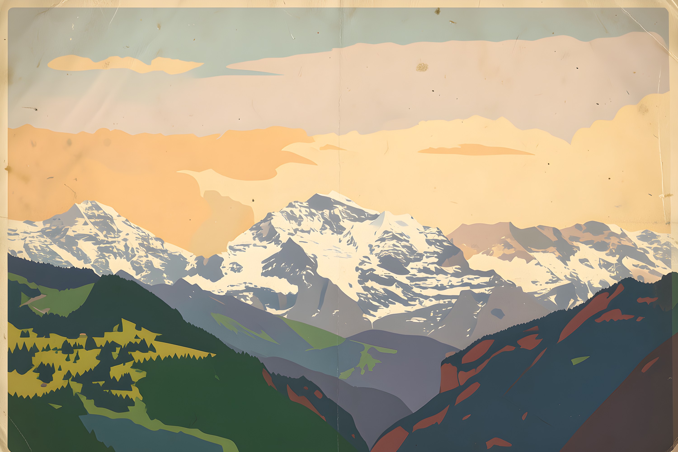
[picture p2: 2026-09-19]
Photos/looks/_DSC8307-Enhanced-NR/13_poster.jpg

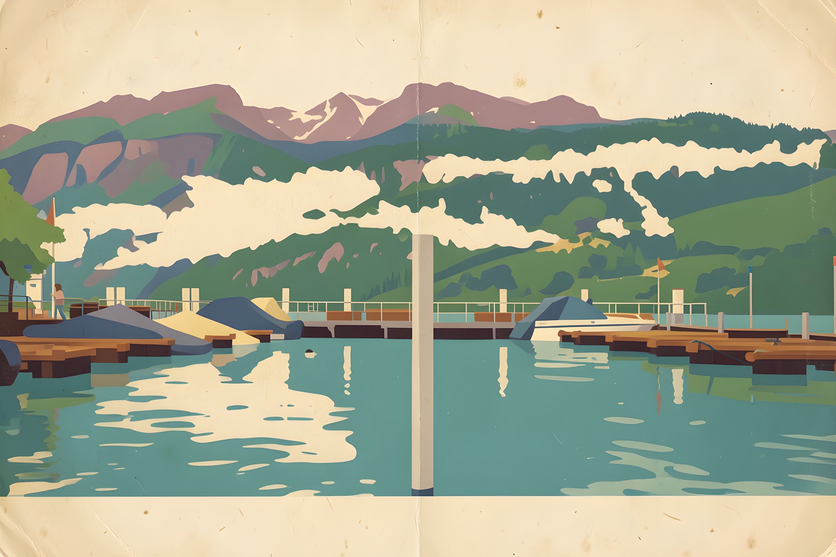
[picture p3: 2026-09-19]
Photos/looks/_DSC8705-Enhanced-NR/13_poster.jpg

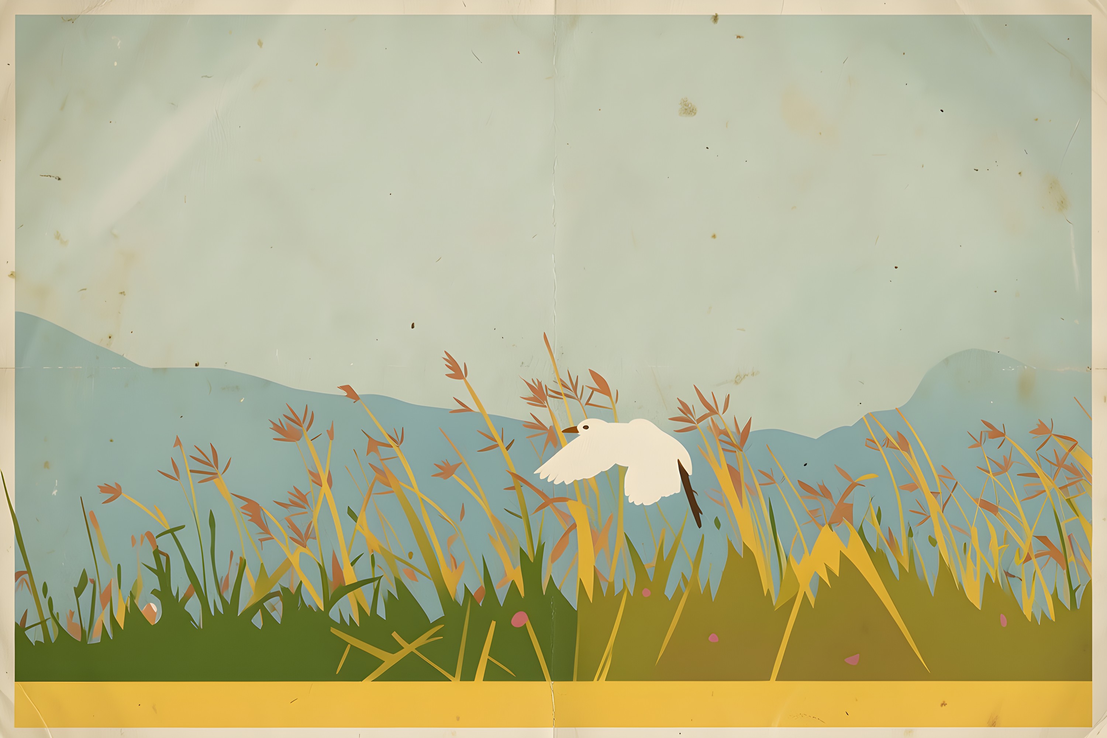
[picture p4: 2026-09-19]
Photos/looks/DSC06684-Enhanced-NR/13_poster.jpg

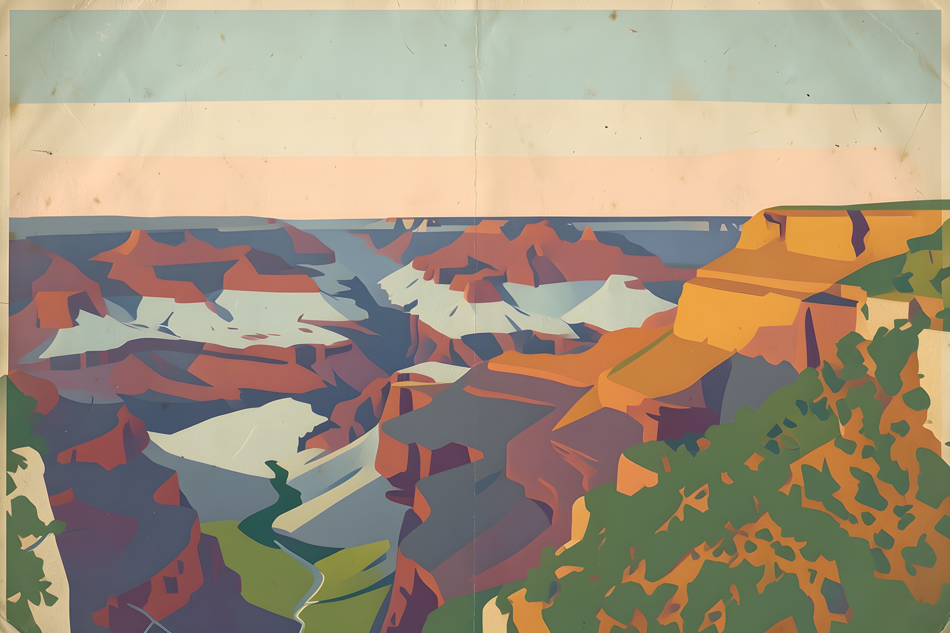
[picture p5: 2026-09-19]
Photos/looks/DSC00272-Enhanced-NR/13_poster.jpg

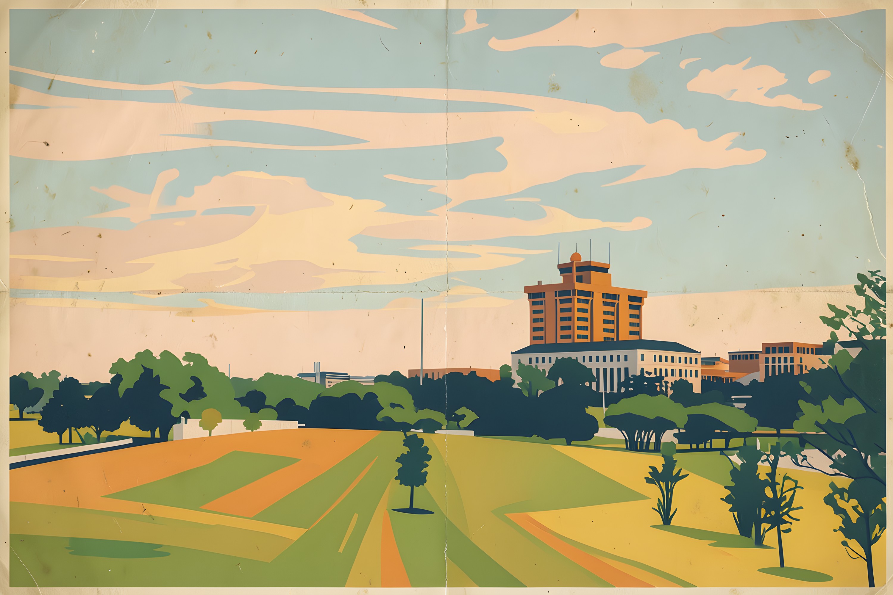
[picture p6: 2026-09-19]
Photos/looks/IMG_0223/13_poster.jpg

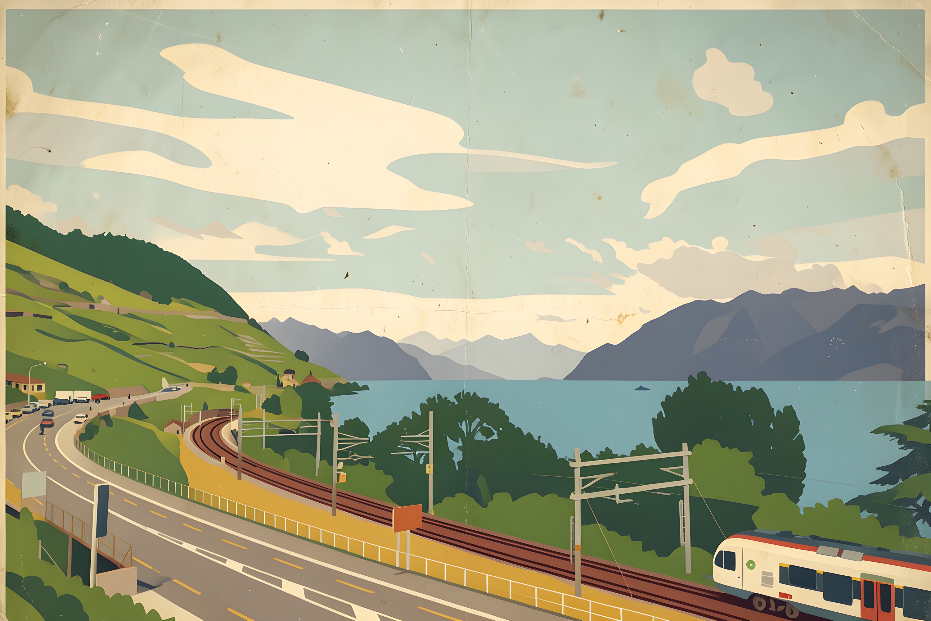
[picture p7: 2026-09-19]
Photos/looks/_DSC7022-Enhanced-NR/13_poster.jpg

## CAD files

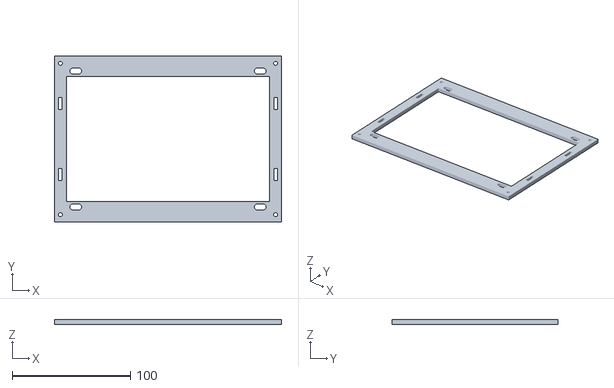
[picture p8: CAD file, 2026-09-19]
design/modular-camera/inputs/01_screen_frame_192x140x4.stl
192.0 x 140.0 x 4.00

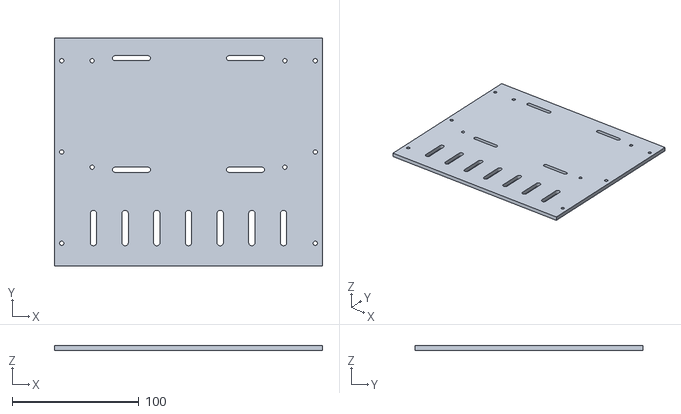
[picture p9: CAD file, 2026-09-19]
design/modular-camera/stl/02_base.stl
211.4 x 180.0 x 4.00

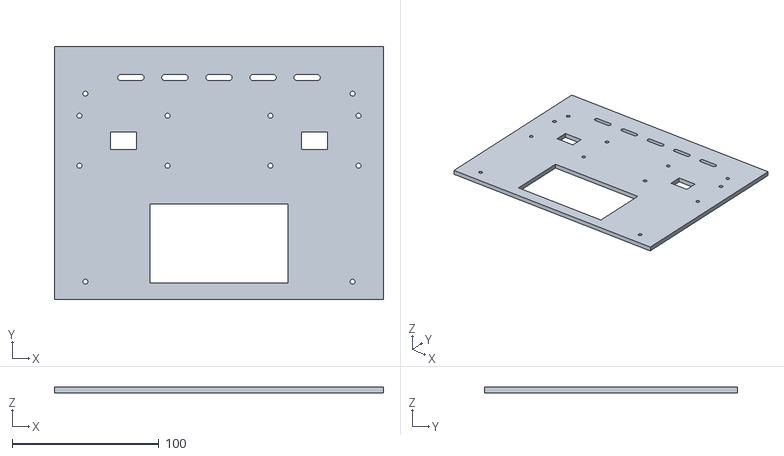
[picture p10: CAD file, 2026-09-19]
design/modular-camera/stl/06_replaceable_front.stl
224.0 x 172.0 x 4.00

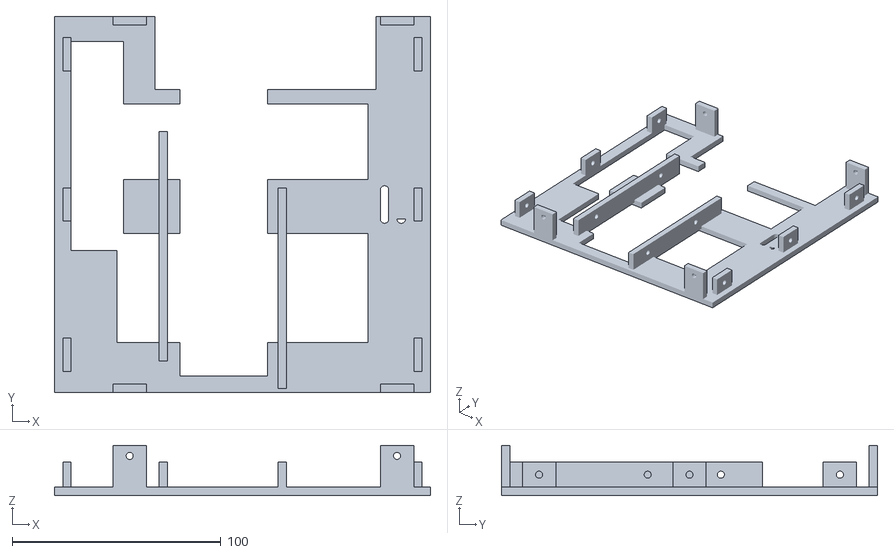
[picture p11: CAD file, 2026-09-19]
design/modular-camera/stl/04_right_side.stl
180.0 x 180.0 x 24.0

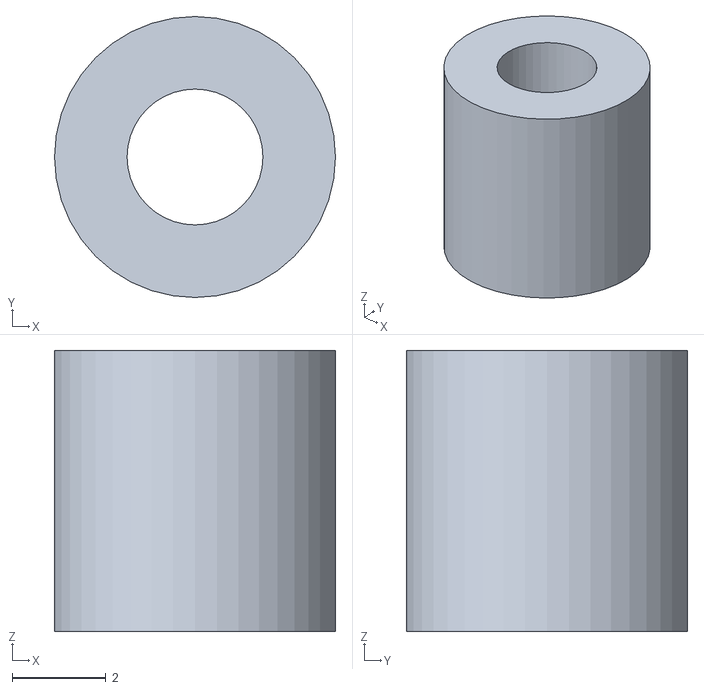
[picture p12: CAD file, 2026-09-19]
design/modular-camera/stl/11_Pi_M2p5_spacer_6mm_PRINT_4.stl
6.00 x 6.00 x 6.00

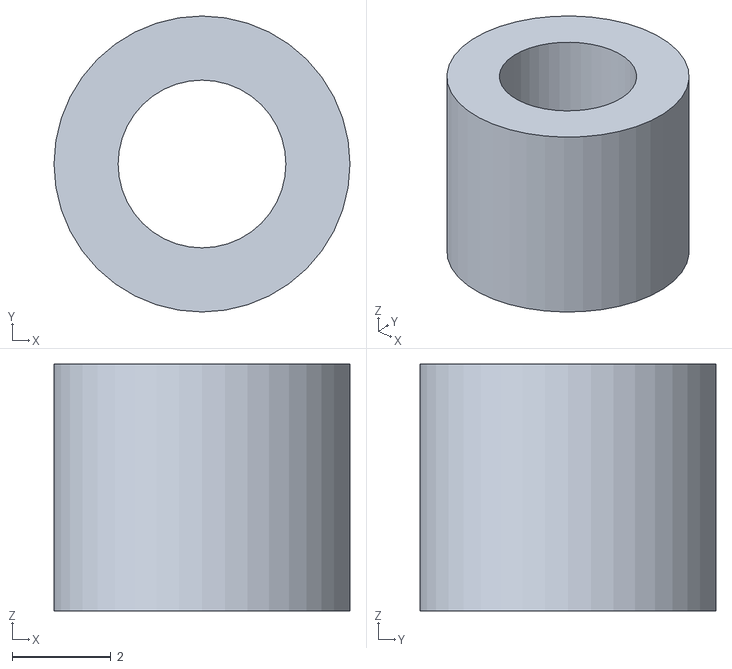
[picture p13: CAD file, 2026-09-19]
design/modular-camera/stl/13_sensor_spacer_5mm_AS_NEEDED.stl
6.00 x 6.00 x 5.00

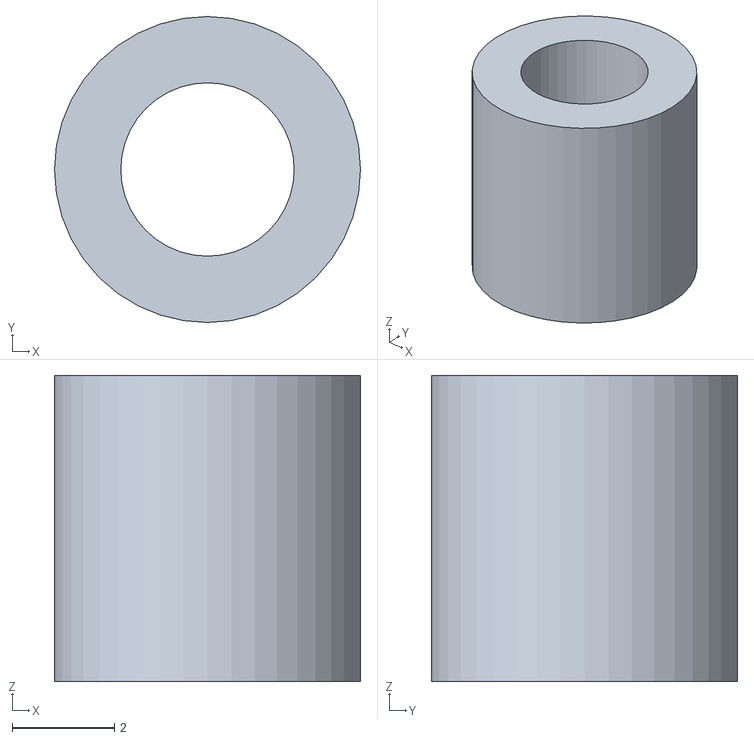
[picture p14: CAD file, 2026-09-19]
design/modular-camera/stl/12_UNO_M3_spacer_6mm_PRINT_4.stl
6.00 x 6.00 x 6.00

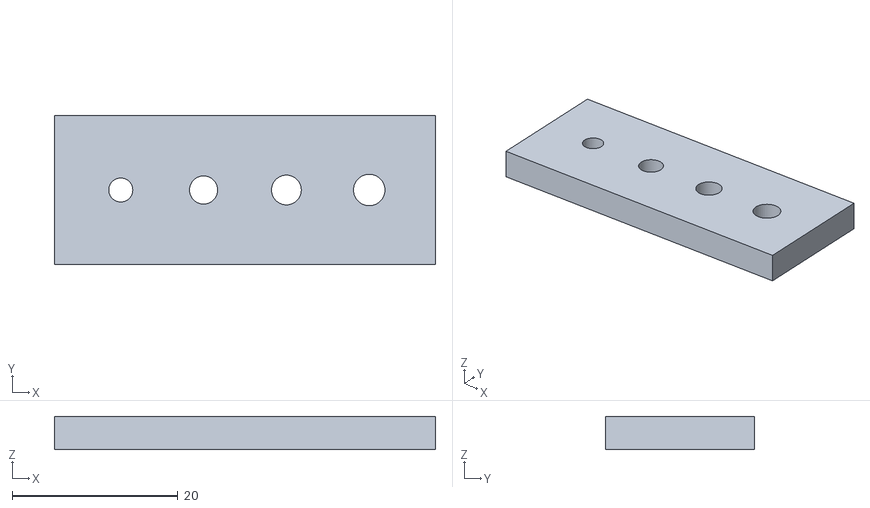
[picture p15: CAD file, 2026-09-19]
design/modular-camera/stl/15_fastener_fit_coupon.stl
46.0 x 18.0 x 4.00

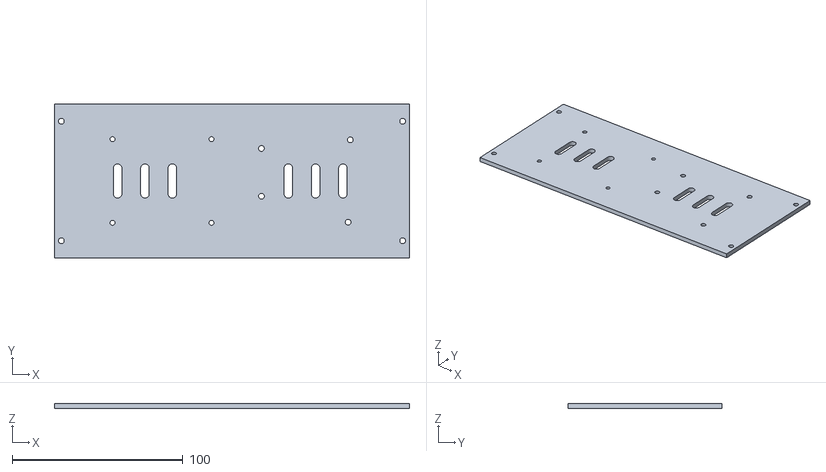
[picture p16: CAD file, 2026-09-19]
design/modular-camera/stl/07_Pi4_and_UNOQ_shelf.stl
208.0 x 90.0 x 3.00

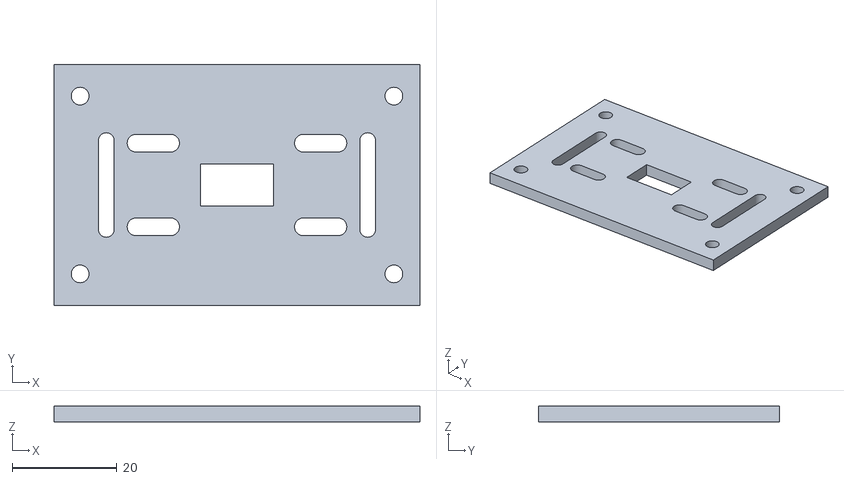
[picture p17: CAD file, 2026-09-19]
design/modular-camera/stl/10_sensor_control_carrier_PRINT_5.stl
70.0 x 46.0 x 3.00

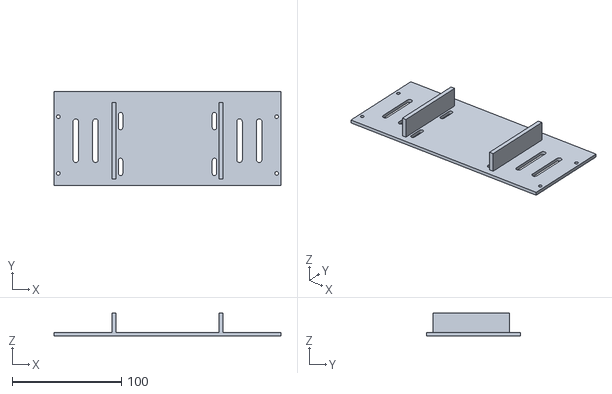
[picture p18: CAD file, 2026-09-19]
design/modular-camera/stl/08_Logitech_clip_cradle.stl
208.0 x 86.0 x 21.0

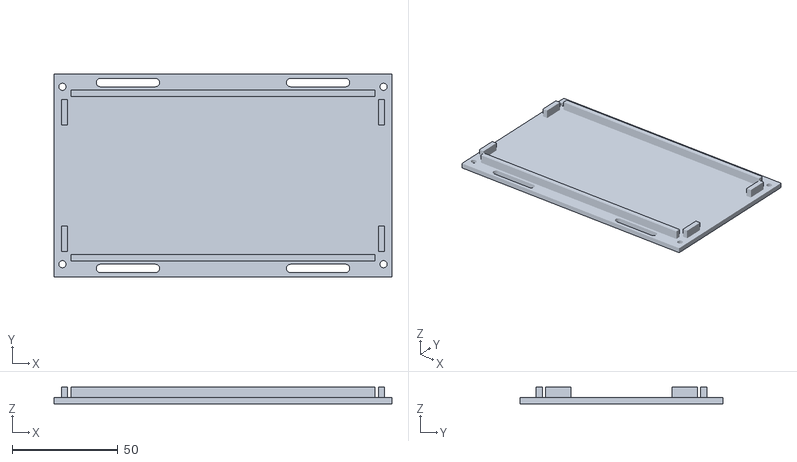
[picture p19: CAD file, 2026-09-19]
design/modular-camera/stl/09_Anker_strap_cradle.stl
160.0 x 96.0 x 8.00

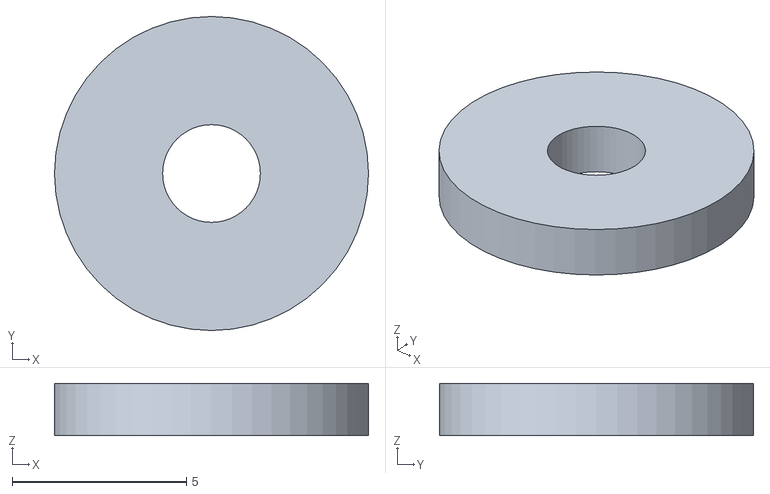
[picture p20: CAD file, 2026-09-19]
design/modular-camera/inputs/04_washer_PRINT_FOUR.stl
9.00 x 9.00 x 1.50

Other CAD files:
design/modular-camera/stl/01_rear_screen_frame.stl
design/modular-camera/stl/03_left_side.stl
design/modular-camera/stl/05_removable_roof.stl
design/modular-camera/stl/14_screen_tab_washer_PRINT_4.stl
design/modular-camera/nimbus-modular-camera.blend

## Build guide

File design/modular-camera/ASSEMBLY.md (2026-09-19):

# Print and assemble in stages

## Before the first plate

1. Confirm the physical parts match the listed **Pi 4B, UNO Q, C270 and Anker A110D**. A different revision, fitted Pi case or taller cooler changes the fit.
2. Obtain through-bolts, matching nuts and washers. HackMIT's inventory listed an M3 assortment but **0/1 available** when checked; availability is not possession. Do not start all structural prints assuming fasteners will appear.
3. Print `15_fastener_fit_coupon` and `01_rear_screen_frame`. If the screen-holder R02 is already printed, reuse it instead. Coupon holes are 2.9, 3.4, 3.6 and 3.8 mm, in order from one end to the other; distinguish ends by the visibly smallest hole. Test your actual bolts without forcing them.
4. Place the unpowered screen against the frame. Confirm all four tab positions fall within the slots, screen edges do not press against the plastic, and right-side HDMI/USB plugs can be inserted. Use the small tab screws/washer arrangement below; **do not drive M3 screws into the roughly 3 mm screen tab holes by force**.

## Print settings — starting point, not a sliced job

- Use the site's PLA / 0.4 mm nozzle configuration. Start at 0.20 mm layers, four perimeters, five top/bottom layers and about 20–25% infill; staff may adjust for their filament/printer.
- STLs are already oriented flat on Z=0. Sides print with their outside faces on the bed and attachment lugs upward. Cradles print with their flat undersides down.
- Inspect every layer preview, especially the horizontal small bolt bores in the side lugs. Use local supports only if the slicer/operator judges them necessary; do not indiscriminately fill all slots with support.
- Largest part is 224 mm across, within the 256 mm bed. Allow room for brim/purge/adhesion features and accept the slicer's actual printable-area check.
- Avoid stacking parts or changing scale to fit. Print time, filament mass and number of plates require actual slicing; none are claimed here.
- Tiny spacers may need brims. Purchased insulating spacers of the same height can replace printed ones after checking outside clearance.

## Fasteners and straps

All major chassis bores are **3.4 mm clearance for M3 through-bolts**, not modeled threads. Nuts remain accessible through the open side frames. Use washers and tighten gently; PLA creeps and excessive tightening cracks thin features.

| Connection | Quantity | Starting fastener choice; verify stack before tightening |
|---|---:|---|
| Floor to side lugs | 6 | M3 × 16 mm + nuts/washers |
| Roof to side lugs | 6 | M3 × 16 mm + nuts/washers |
| Rear screen FRAME to side lugs | 4 | M3 × 16 mm + nuts/washers; separate from screen PCB tabs |
| Front panel to side lugs | 4 | M3 × 16 mm + nuts/washers |
| Electronics shelf to side ledges | 4 | M3 × 12–16 mm + nuts/washers |
| Webcam shelf to side ledges | 4 | M3 × 12–16 mm + nuts/washers |
| Battery cradle to floor | 4 | M3 × 12–16 mm + nuts/washers |
| Sensor carrier to roof/front | 4 per carrier, up to 20 | M3 × 12–16 mm + nuts/washers |
| Pi board through 6 mm spacers/shelf | 4 | M2.5 × 14–16 mm + nuts/insulating washers |
| UNO Q board through 6 mm spacers/shelf | 4 | M3 × 14–16 mm + nuts/insulating washers |
| Sensor PCB through 5 mm spacers/carrier | Up to 4 per PCB | Usually M3 × 14–16 mm **only if actual holes accept it**; otherwise insulated strap mounting |
| Screen tabs to rear frame | 4 | M2 or M2.5 with printed tab washers and nuts; select length after checking actual tab stack, not nominal M3 |

Structural subtotal with all five carriers: **52 M3 bolt/nut pairs**, plus 4 for UNO Q and up to 20 for sensor boards. Pi and screen use separate smaller hardware. An assortment of lengths is more useful than buying one length blindly; no bolt end may contact an electronic component or connector.

Bring two soft straps for the battery and one or two for the webcam clip, non-slip padding, and small ties for cable strain relief. Straps must fit the 4 mm-wide slot openings. Thin zip ties can locate parts temporarily, but are not a tested substitute for structural fasteners. Do not tie across the camera lens/microphone, battery ports or PCB components.

## Assembly sequence

1. **Prepare floor and battery cradle.** Feed the battery straps through the matching slots in BOTH pieces before fastening the cradle to the floor. Screw holes are on a 152 × 84 mm rectangle. Put the Anker between the low guides with controls/ports reachable. Strap gently; no adhesive is needed on the battery itself. Leave it disconnected during assembly.
2. **Attach the two side frames to the floor.** The long inward ledges belong inside; rear is the screen side. Floor is below its lugs, roof above its lugs. Leave bolts slightly loose until the panels are squared.
3. **Build the electronics shelf on the bench.** Four 6 mm spacers under each board; Pi's 2.9 mm holes use M2.5, UNO Q's 3.4 mm holes use M3. The patterns are intentionally different. Pi large USB/Ethernet ports point toward the left service opening; UNO Q USB-C points toward the right. Test connectors and underside clearance before fastening the shelf onto the lower ledges. Keep small parts away from powered boards.
4. **Fit webcam shelf.** Fasten it to the upper ledges. Place the intact C270/clip between its guide walls, use non-slip padding and adjustable straps. Its face is near the front opening and the USB cable routes rearward/sideways. Camera clip angle and optical aim are physical fit checks, not determined by the placeholder box in the render. Secure the clip/base, never the optical face.
5. **Mount screen to its separate frame**, gently fastening through the elongated tab slots with washers. No load should press on glass, flex cables or display components. Plug in its cables while access is open, then fasten the FRAME's four outer chassis holes to the rear lugs. The screen PCB tab screws do not join the chassis.
6. **Add front and sensor carriers.** Front panel bolts to four lugs. Optional front carriers can hold Distance and thermal/spare boards; keep their optical/thermal sensing faces exposed. Generic slots do not certify an unknown module's mounting pattern. Route cables through the center opening with insulating spacers and strain relief.
7. **Wire/test before adding roof.** Capture a picture, operate the screen, and verify selected control/sensor data using the intended computer. Check every USB/HDMI connector can be removed without dismantling a board. Do not power both computers or backfeed ports using unverified splitter wiring.
8. **Fit roof last.** Suggested carrier locations: Buttons (front-left), Light (front-right), Movement (rear-right). Install only needed carriers and connect their cables before closing. The buttons themselves remain accessible on the real PCB; no precision plunger mechanism is required.
9. **Bench test under load.** Confirm no power resets, screen dropouts, hot trapped cables, fan obstructions or battery stress. Test lifting gently over a table; strap slots are not proof of carrying strength.

## Interfaces retained for future changes

- Screen frame outside: 192 × 140 × 4 mm; outer chassis pitch **182 × 128 mm**.
- Screen-tab slot nominal pitch **156 × 115 mm**, each slot 10 × 5 mm; central opening 172 × 106 mm. Based on your measurements, not a manufacturer-certified screen drawing.
- Front is removable independently of the webcam shelf; aperture is 94 × 54 mm. Swap only this panel for later styling.
- Each sensor carrier is 70 × 46 × 3 mm, outer attachment pitch **60 × 34 mm**. PCB slots accommodate a nominal 32 × 16 mm four-hole footprint with horizontal adjustment; other modules can use the tie slots with insulation.
- Both computer footprints are already present on the shelf; unused space can remain empty. A USB hub is not implicitly mounted inside this design.

## Remaining physical checks

These are practical fit tests, not requests to measure every component precisely:

- Screen tab fit and thickness, washer seating and real connector bend radius.
- C270 clip pose, stable aim, lens/microphone unobstructed, safe cable exit.
- Pi fitted cooling assembly within the allocated **37 mm above PCB bottom**; UNO Q within the allocated **25 mm**. These are design allowances, not measured manufacturer heights.
- Power-bank port orientation and built-in lead routing; battery can slide out after straps are released.
- Actual sensor board hole patterns, exposed sensing direction, and enough cable length to remove the roof without yanking connectors.
- Fastener access/protrusion and print shrinkage. Relieve only plastic as needed, not holes in electronics.
- Full operating power and temperature test before expecting portable standalone operation.

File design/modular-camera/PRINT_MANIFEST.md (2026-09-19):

# Print manifest — Nimbus modular camera R01

Individual STLs; millimetres; print at 100%. Fit and strength not physically tested.

| File | Copies | Print dimensions (mm) |
|---|---:|---|
| 01_rear_screen_frame.stl | 1 | 192.0 × 140.0 × 4.0 |
| 02_base.stl | 1 | 211.4 × 180.0 × 4.0 |
| 03_left_side.stl | 1 | 180.0 × 180.0 × 24.0 |
| 04_right_side.stl | 1 | 180.0 × 180.0 × 24.0 |
| 05_removable_roof.stl | 1 | 211.4 × 180.0 × 4.0 |
| 06_replaceable_front.stl | 1 | 224.0 × 172.0 × 4.0 |
| 07_Pi4_and_UNOQ_shelf.stl | 1 | 208.0 × 90.0 × 3.0 |
| 08_Logitech_clip_cradle.stl | 1 | 208.0 × 86.0 × 21.0 |
| 09_Anker_strap_cradle.stl | 1 | 160.0 × 96.0 × 8.0 |
| 10_sensor_control_carrier_PRINT_5.stl | 5 | 70.0 × 46.0 × 3.0 |
| 11_Pi_M2p5_spacer_6mm_PRINT_4.stl | 4 | 6.0 × 6.0 × 6.0 |
| 12_UNO_M3_spacer_6mm_PRINT_4.stl | 4 | 6.0 × 6.0 × 6.0 |
| 13_sensor_spacer_5mm_AS_NEEDED.stl | 20 | 6.0 × 6.0 × 5.0 |
| 14_screen_tab_washer_PRINT_4.stl | 4 | 9.0 × 9.0 × 1.5 |
| 15_fastener_fit_coupon.stl | 1 | 46.0 × 18.0 × 4.0 |

Sensor spacer quantity is a maximum provision, not a requirement. Print only the sensor carriers you use.
Print screen/frame and fastener coupon first; do not duplicate an already printed screen holder.

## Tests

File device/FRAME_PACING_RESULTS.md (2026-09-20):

# Pi bottleneck analysis — 2026-09-20

24–30 FPS has not been demonstrated on the real display. The measurements below
are completed UI callbacks, not physical scanout measurements. Some intervals
include user-triggered capture/review transitions, so they are not controlled
scene comparisons.

## Recorded evidence

Source: `/tmp/hackmit-frame-pacing-results/reuse-fps-30.json`, a 61.43-second
process/thermal sample with aggregate screen logs, including earlier warm-up.

| Path/window | Measured result |
| --- | --- |
| Representative home window | 17.50 callbacks/s; render p50 22.673 ms; Tk upload p50 24.022 ms; callback p50 47.084 ms |
| Stable review windows | 21.05–21.17 callbacks/s; callback p50 38.144–38.677 ms |
| Transition/warm-up tails | Render maxima 527, 741, and 986 ms; largest callback 1012 ms |
| Process CPU | Python approximately 79–90%, Xwayland approximately 50–61%, each relative to one core |
| Thermal | Approximately 64–65 °C; `throttled=0x0` |

A 30 FPS frame has 33.33 ms; 24 FPS has 41.67 ms. The representative home
callback already exceeds both budgets before the cooperative scheduling delay.
Persistent Tk image reuse removed the prior label reconfiguration cost, but
upload alone still consumes about 24–25 ms. The evidence points to serial
render/presentation cost, not thermal throttling or exhaustion of every CPU core.

## Separate latency problems

1. `Screen._tick` renders and uploads synchronously on the Tk event thread.
   Touch processing cannot run during those calls. Long render spikes therefore
   delay both animations and input feedback.
2. `Screen._photo` decodes images and, on a local miss, performs an HTTP request
   with a 10-second timeout on that same thread. Product images also decode on
   the drawing path. This is a confirmed blocking path, but current aggregate
   logs do not attribute individual spikes to it. Review and adapt Devin's
   background loader against the current UI before integration.
3. Shutter actions dispatch on touch release to a background worker. Capture
   then includes camera exposure settling, sensor reads, and potentially remote
   AI processing. These durations must be measured separately from immediate
   pressed/busy feedback; a faster renderer cannot remove remote service time.
4. Returning to the viewfinder currently queries the library before checking
   the requested destination. This is avoidable UI-thread work on the Back/Esc
   path, though no timing yet establishes its contribution.

## Highest-value next experiment

Sol implemented a persistent C++ SDL2 streaming-texture presenter with Python
bindings, input events, renderer diagnostics, and a benchmark. It is present in
integration commit `16c21c4` but is not wired into the production UI. Its local
dummy/software timings are ABI validation only, not a prediction of Pi speed.

At the representative 22.7 ms render median, 30 FPS leaves approximately
10.6 ms for conversion, presentation, event handling, and scheduling. SDL is
therefore a plausible route, not a verified result. Test the real accelerated
backend, then measure actual home/cloud/capture transitions and tail latency.
Most Pillow/OpenCV/NumPy pixel operations already execute compiled code;
rewriting Python orchestration alone does not address the measured upload cost.

Fresh hardware testing is currently blocked: SSH timed out twice and Tailscale
reported the Pi offline, last seen seven minutes earlier. No new deployment or
restart was performed during this analysis.

## Reconnection and SDL hardware probe

After joining Calvin's saved hotspot, the Pi recovered without a reboot. The
native library compiled on the Pi using extracted SDL2 headers and its existing
runtime. Five-second 1024x600 static-frame probes at 30 FPS completed 150 frames
without missed deadlines:

| SDL backend | Whole-call p50 / p95 | Upload p50 | Process CPU, one-core scale |
| --- | --- | --- | --- |
| X11 / OpenGL accelerated | 14.922 / 21.950 ms | 13.146 ms | 43.7% |
| Wayland / OpenGL accelerated | 13.668 / 20.227 ms | 12.250 ms | 40.6% |

Vsync was disabled. The existing camera app was still running during these
probes, so contention is a confounder. These results establish real Pi backend
availability and static upload throughput, not full-app FPS or visible smoothness.
The opt-in UI integration has headless coverage for pixel forwarding, fallback,
pointer release outside the window, and suppression of repeated shutter keys.
The initial integration suite passed 110 tests with two native-build skips.

The Pi then became unreachable again during candidate transfer. ASUS remained
reachable on the same hotspot but could reach neither Pi port 22 on its last
local IP nor its Tailscale peer. The app restart command did not connect. Full
application SDL measurements remain outstanding; do not claim 24–30 FPS achieved.

## Live application at 24 FPS

Connectivity recovered and the opt-in UI was deployed with SDL Wayland/OpenGL,
acceleration required, vsync disabled, and a 24 FPS target. The saved
`sdl-home-24.json` contains a 61.11-second resource sample and frame logs. After
the startup interval (20.37 callbacks/s), six consecutive intervals measured
23.91–23.95 callbacks/s with zero render failures. Representative median total
frame work was 31–33 ms, including 9–10 ms presentation and RGB extraction.
Temperature stayed 63.8–65.2 °C with no throttling. Process CPU was 133.5% of one
core; Xwayland was 0% in the final sample. Later live intervals measured
24.00, 23.98, and 24.01 callbacks/s.

These establish approximately 24 completed frames/s on the live home screen,
not perfectly uniform scanout or a verified capture/review experience. Startup
and occasional missed deadlines remain. The initial stats label incorrectly
called native presentation “Tk image/upload”; it is now backend-neutral.

The Pi was switched successfully to the user's saved `iPh16P-Adi` hotspot after
its signal measured 100 versus 44 for Calvin's. A temporary test driver then
scheduled shutter press/release, observed busy/review states, and scheduled a
separate local-camera review cycle. Automatic posting is forcibly disabled in
that driver. Capture API `172.20.10.12:8000` was unreachable before the test;
therefore remote AI completion must not be inferred from display throughput.

## Scripted capture/review acceptance

The test driver invoked the existing touch-down/up handlers at the shutter
coordinates, observed state from the UI loop, exercised the real webcam, and
returned from photo review to preview. This is not physical touchscreen or
photon-latency validation. It disabled automatic posting and never printed.

- Initial shutter release-to-observed-busy: 355 ms. Preparing fixed cloud art
  at startup reduced this to 41 ms in the next run and 43 ms in the final run.
- A profile identified lazy AI SDK/model initialization during capture. Moving
  client resource initialization before the interactive UI (without issuing a
  request) improved the transition interval from about 19 to 22.25 callbacks/s.
- Final local camera acquired a 1280x720 JPEG in 230 ms; earlier cycles took
  921–937 ms. Exposure-settle branches and buffering make these variable, so
  this is not a claim that every capture takes 230 ms.
- Review settled at 24.00 callbacks/s; return to preview settled at
  23.96–24.00. No render errors. Final temperature 62.8 °C, throttling 0x0.
- Capture/reveal are not uniformly 24 FPS: final transition intervals measured
  22.25–22.81 callbacks/s, with a worst callback around 249 ms. The initial
  reveal still includes synchronous photo decoding/composition. Background
  image loading and further frame-age work remain outstanding.
- Remote AI capture did not complete: the configured API at
  172.20.10.12:8000 was unreachable after the network change. The local photo
  review cycle was separate and must not be reported as successful AI capture.

Runtime source commit: `595bfc2`. The normal launcher now defaults to
NIMBUS_UI_BACKEND=sdl, NIMBUS_UI_FPS=24, SDL_VIDEODRIVER=wayland, and diagnostics
enabled. Environment overrides remain possible. The pre-change launcher and
source files are backed up under `~/frame-pacing-test-20260920/original/`.
`camera-release.json` records deployed hashes, the selected backend, and these
validation limits. Revert presentation with NIMBUS_UI_BACKEND=tk (and optionally
NIMBUS_UI_FPS=15) when invoking the launcher. The temporary test driver was
removed from the running path after acceptance.

Offline validation: 113 device tests passed, two native-build tests skipped on
the root checkout. The C++ library compiled and ran on the Pi. A pixel-parity
test compares prepared versus lazy curtain frames. Review/capture behavior,
failure fallback, and native input routing have focused headless coverage;
manual physical touch and scanout validation remain outstanding.

## Remote capture recovered

The old DHCP API address was replaced by persistent SSH forwarding over stable
Tailscale device addresses; see NETWORK_RECOVERY.md. With Pi on Adi's hotspot
and ASUS on Calvin's, both API and Elasticsearch returned HTTP 200. A real AI
capture completed in 23.505 seconds and reported subject unaltered/verified.
The UI reached review without the separate local-camera fallback. This resolves
the previously recorded network failure, not all transient rendering hitches.
Automatic posting was disabled during this acceptance run.

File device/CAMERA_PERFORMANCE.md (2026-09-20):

# Background camera reader review

2026-09-20. Devin SWE-2 proposed and implemented the single-reader design
(commit `10f062b`). Codex independently reviewed, tested, and hardened it.
The branch includes main's `a478172` stable webcam-name lookup.

## Review findings and corrections

The original implementation passed 49 tests, but independent fault injection showed:

- A native read that stalled indefinitely kept returning the old preview forever.
- `close()` released VideoCapture after a two-second join even when its thread was
  still reading. Concurrent release/read can corrupt a native backend.

The reviewed version expires the slot after 1.5 seconds without a completed read,
leaves release to the reader, wakes pending capture callers on close, rejects
captures after close, and stops capture work at cancellation/deadline checkpoints.
Failed settle reads abort and restore automatic exposure. Exposure subprocesses
have timeouts. Initialisation failures also close the camera. Reconnect resolves
its stable device name again.

A wedged native read cannot be safely killed by this thread design: close returns
within its join timeout, while the daemon releases the device when read returns.
Do not interpret caller timeouts as a guarantee that native device I/O terminated.
The receipt timestamp only expires app-held frames; it does not measure exposure
age or prove new exposure settings have reached the sensor. Existing conservative
8-settle/3-capture read semantics are preserved rather than claiming timestamp
freshness. The UI's approximately 15 FPS limit is unchanged.

## Independent validation

- Device suite: 53 passed (including four added stall/shutdown/failure regressions).
- Pipeline suite: 106 passed; pre-existing deprecation warnings only.
- Physical Pi status observed before tests: configured 1280x720 MJPG, 30 FPS,
  no reported throttling, 63.3 C. Configured FPS is not measured delivery FPS.
- No running camera application was replaced or restarted. No photos were captured,
  printed, posted, or sent to AI services by the benchmark.

## Pi synthetic benchmark

`device/tools/bench_preview.py` runs the **actual Camera class**, real 720p JPEG
decode/conversion, and real skin renderer. It replaces VideoCapture with a synthetic
random-noise MJPEG source with >=33 ms read pacing and 100 ms stalls every 30 reads.
It excludes one second of warmup, then measures eight seconds per version.
There is no Tk upload, screen presentation, or physical camera in this benchmark.
The live app remained running, so machine load was not isolated. Noise JPEGs are
an intentionally demanding synthetic input; CPU deltas are not a prediction of
production-camera CPU consumption.

Baseline: `a0daec4` hw.py. Candidate: hardened reader before the stable-name merge
(the merge changes device lookup, not the benchmarked read/render loop).

| Metric | Baseline | Reviewed reader |
|---|---:|---:|
| Camera.frame p50 | 27.445 ms | 0.019 ms |
| Camera.frame p95 | 33.480 ms | 0.041 ms |
| Camera + skin p50 | 56.851 ms | 32.551 ms |
| Camera + skin p95 | 68.040 ms | 47.389 ms |
| Camera + skin maximum | 168.994 ms | 55.536 ms |
| Completed loop iterations/sec | 13.94 | 15.06 |
| Benchmark process CPU (% of one core) | 99.9% | 152.8% |

The measured benefit is nonblocking preview access and improved simulated loop
responsiveness. The cost is about 53 percentage points of one core in this workload.
This does not establish physical camera-to-screen latency, image quality after
exposure changes, or production power/thermal behavior. Those require a live A/B.

Reproduce from the device directory:

```sh
git show a0daec4:device/nimbus_cam/hw.py > /tmp/nimbus-baseline-hw.py
uv run python tools/bench_preview.py /tmp/nimbus-baseline-hw.py
uv run python tools/bench_preview.py
```

The earlier Devin benchmark simulated a particular four-frame queue and reimplemented
the read path; its frame-age predictions were not physical measurements. It has been
replaced with this actual-code benchmark. Verdict: useful responsiveness improvement,
with lifecycle fixes required and a measurable CPU tradeoff; not a validated live
camera deployment.

## Hidden-preview decode suppression (not deployed)

V4L2 previews now drain compressed frames with `grab()` while photo screens or a
fully closed curtain hide the feed. Visible previews and shutter reads retain the
existing decoding path. Camera-derived light sensing requests a fresh decoded
frame on demand; other backends retain continuous decoding.

The screen prewarms before a scheduled curtain opening. For an unannounced return,
it keeps the previous photo scene or animated closed curtain until a fresh frame
arrives, without blocking Tk. Touch actions are suppressed during that handover.
A one-second monotonic deadline prevents a disconnected camera from trapping the
user on the previous scene. The normal unavailable-camera display then resumes.
The reader also retrieves its current buffer if visibility changes during grab,
rather than unnecessarily waiting for another acquisition.

This fixes the blank flash, but does not make camera warmup instantaneous: a direct
return can defer the reveal until the next fresh decoded frame and UI tick. No
claim of strict latency equivalence or measured thermal reduction is made. Physical
Pi touchscreen/webcam A/B testing remains outstanding. Validation: 65 device tests
pass, including photo return, late cloud completion, failed-resume timeout,
real-render preservation of the photo controls, and the sensor-slot invalidation
race reproduced during adversarial review. Both adversarial findings were fixed:
the controls remain drawn while hit targets are disabled, and sensor results use
a single local snapshot of the shared frame slot.

## Integration with current main (2026-09-20)

Integrated onto 3b81a77 for a controlled Pi deployment. Preserved f319a0c's
proportional gain/exposure calculation inside the reader-thread shutter path,
including the gain-ceiling fallback. Added both cases as regressions and updated
the older test that expected unconditional maximum gain. Current shop and app
changes are retained. Historical not-deployed statements above describe earlier
review stages; deployment status is recorded separately after hardware checks.

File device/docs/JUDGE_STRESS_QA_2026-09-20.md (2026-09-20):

# Judge-style stress testing — September 20, 2026

198 device tests and 106 pipeline tests passed. The device suite includes 27 new
stress/integration cases. Pipeline tests emitted deprecation warnings, not failures.

Two bugs were reproduced before fixing them:

- Simultaneous shutter calls waited on a lock and each generated another photo.
  Capture now rejects concurrent requests immediately, including GPIO/voice calls.
- Back fetched gallery data before returning to preview. A disconnected library
  could block the UI or prevent Back entirely. Returning to the camera is now local.

## Coverage

| Scenario | Result / scope |
|---|---|
| Eight simultaneous capture requests | Live Pi: one generation, seven rejections, one successful review |
| Back with unreachable photo library | Live fault injection: returned to viewfinder in 0.03 ms; four screen regression cases pass |
| Gallery next, previous, index 0 and index 999 | Live: valid bounded indices, no errors; empty/single-photo cases also tested |
| Mode changes and invalid mode | Live: Visa Buy and AI Camera accepted; invalid mode rejected |
| Camera capture failure | Injected live error cleared busy; subsequent real JPEG acquisition returned 1280×720 |
| Network/camera/malformed-response exceptions | Four app-level failure/recovery cases pass |
| Missing/corrupt local image | Real decoder/async UI tests recover using downloaded image |
| Missing/corrupt remote image | Placeholder shown, loading state clears, no permanent closed curtain |
| Peer disconnect | Real local HTTP socket tests: POST once, GET at most twice |
| Recoverable download disconnect | Real socket test recovers on the second connection |
| HTTP 401/404/429/500/503 | No automatic POST replay |
| Stale image completion, queue pressure, cache eviction, shutdown | Existing bounded loader tests pass |
| Cold model cache / restart | Previous acceptance verified persistent offline model loading; interactive app restarted after this run |
| GPU unavailable, API lifecycle, subject preservation, render fallback | Pipeline tests pass using isolated fixtures |
| Printer errors and job handling | Pipeline tests use mocked printer operations; no live printing |

## Live evidence

The Pi used the release source with the two fixes, accelerated SDL and a 24 FPS
request. The eight-request burst began at 22.564 seconds; review completed at
51.299 seconds. Prepare, finish and photo download all returned HTTP 200 in
248 ms, 15.037 seconds and 147 ms. Gallery and recovery checks finished at
70.580 seconds with `screen=viewfinder`, `busy=false`, and one actual generation.
There were no render failures or unexpected capture errors. The logged
`Capture failed: injected camera disconnect` is the intentional failure test.

Raw evidence on the Pi: `~/camera-latency-qa/judge-events.json` and
`~/camera-latency-qa/judge-e2e.log`. Temporary driver:
`~/camera-latency-qa/judge-e2e.py`. It disables voice and automatic posting and
blocks posting, purchasing, printing and sending to phone. Burst calls exercise
the shared app entry point; they are not eight physical button presses.

## Remaining demo risks

The Pi was charging and reported active undervoltage (`0x50005`). Rendering was
variable, with a 1.591-second callback during reveal. These functional passes do
not certify smooth 24 FPS or camera motion latency. Stable-power performance
acceptance remains outstanding.

Live voice recognition, purchases, public posting, phone sharing, real printer
output and physical cable disconnects were not exercised. No device reboot or
network-service shutdown was induced. Fable experiments remain outside main.

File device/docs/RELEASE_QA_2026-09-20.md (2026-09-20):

# Pi release QA, September 20, 2026

This release includes caption wrapping, asynchronous review preparation, shorter
shutter feedback, startup artwork warming, and isolated capture HTTP requests.
Fable's RGBX upload, camera buffering experiments, extra controls cache, and power
experiments remain outside this release. The live experimental tree is preserved
separately; release testing uses its own directory and matching native library.

## Automated checks

The complete device suite passes 171 tests, including both native build tests.
The native presenter builds on macOS and the Pi. Automatic posting is disabled in
all scripted capture tests.

## First live run and reboot regression

The release ran with accelerated SDL/Wayland and a 24 Hz target. Shutter release
to busy feedback was 51 ms. Prepare, finish and photo download returned HTTP 200
in 306 ms, 11.899 seconds and 145 ms respectively. Waiting-animation callback
throughput was usually 23.95–24.01/s, with slower transition intervals. These
are software callback measurements, not physical display scanout measurements.

Review did not appear: a Python stack dump showed `take_photo -> _store_server ->
ElasticLibrary.add -> embed -> TextEmbedding -> Hugging Face model_info` blocked
on a network connection. The default `/tmp/fastembed_cache` was empty after the
reboot. The photo itself had already been downloaded to camera storage.

The embedding model now uses persistent `NIMBUS_CAM_HOME/models` storage,
overridable through `NIMBUS_EMBED_CACHE`, and attempts offline loading first.
New installations still need to provision the model while online; capture still
waits for indexing. The device README includes that setup check.

## Power and remaining limits

Battery-only samples during this session report `get_throttled=0x0`. Earlier
active undervoltage coincided with substantially slower rendering. This does not
prove the battery can support every peripheral or charger transition indefinitely.
No CPU frequency cap is retained. Startup and photo-reveal frames still hitch;
steady 24 Hz throughput is not a claim that every frame meets its deadline.

When the user reconnected the Anker charger, the Pi became unreachable through
its direct Tailscale address. Access through the ASUS and the hotspot LAN showed
a changed boot ID and roughly one minute uptime, confirming a reboot. Active
undervoltage/throttling returned (`0x50005`), CPU frequency was about 600 MHz,
and the restored experimental RGBX preview ran at roughly 15–16 callbacks/s.
The boot launcher retained RGBX and the 24 FPS target as intended. Performance
acceptance at 24 FPS remains pending a stable power source.

## Functional retest while charging

The persistent model loaded successfully with `HF_HUB_OFFLINE=1`, returning a
384-dimensional embedding in 7.925 seconds including import/model startup.
With that cache provisioned, a fresh real capture completed prepare (321 ms),
finish (14.758 seconds), and image download (161 ms), all HTTP 200. Review appeared
28.289 seconds after shutter release; busy feedback took 99 ms. Automatic posting
was disabled. No capture error or render failure was logged.
The generated review image was inspected from a display screenshot. The scripted
return to viewfinder completed, and the run finished with `busy=false`.

This run was undervolted and does not establish normal rendering performance.
The reveal interval included a 1.571-second callback, and throughput fell sharply.
The functional pass must not be interpreted as a smooth-animation acceptance.

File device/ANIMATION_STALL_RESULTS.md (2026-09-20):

# Caption wrapping and photo reveal measurements

Tested on the Pi on September 20, 2026, with accelerated SDL/Wayland, a 24 FPS UI target,
and the separately reviewed camera experiment using two buffers with fresh skipping off.
The camera experiment is not included in this commit or main.

## Change

Wrapping text previously rendered every candidate prefix just to measure its width,
including prefixes beyond the requested visible lines. The new path uses cached font
advance/bounding-box metrics for definite fits, retains the original rendered-width
check for ambiguous boundaries, stops after enough lines, and caches wrapping results.
Font bounds are conservative; no font, size, tracking, layout or image resolution changes.

Tests compare the original visible text with the optimized result across empty strings,
long words, Unicode, tracking, multiple line counts and widths near wrapping boundaries.
Full device suite: 150 passed, 2 skipped (native library not built in the local checkout).

## Pi comparison without profiling

Same latest saved photo, scripted busy curtain at 10 seconds, review at 25 seconds,
and return to preview at 38 seconds. No AI request or posting in this controlled test.

| Measurement | Before | After |
|---|---:|---:|
| Worst callback in photo-reveal interval | 922.598 ms | 235.934 ms |
| Worst render in photo-reveal interval | 911.223 ms | 224.860 ms |
| Throughput in that 10-second interval | 21.39/s | 22.46/s |
| Following steady review interval | 23.91/s | 24.00/s |

This is one sequential comparison, not a distribution of repeated runs. Profiling runs
also showed caption rasterization falling from hundreds of glyph draws to the visible
text. Profiler timing was excluded from the table. Raw logs are retained on the Pi under
`~/camera-latency-qa/timing-before.log` and `timing-after.log`.

## Limits

A 236 ms reveal callback is still visibly slow. First text rasterization, photo decode,
card construction and transforms remain synchronous. Cloud transition intervals still
fall below the 24 FPS target. Callback throughput is neither physical scanout nor
motion-to-photon latency. These measurements do not certify every caption or interaction.

The temporary interactive run uses two camera buffers, skipping disabled, and automatic
posting disabled. The persistent boot launcher was not changed by these experiments.
Pi backups and test launchers are under `~/camera-latency-qa/`. No experimental changes
were pushed to main during this work.

## Follow-up: prepared review cache and shutter feedback

A bounded worker now decodes/fetches photos, prepares the card and static rotation,
and warms caption glyphs before exposing the result to the UI. Four prepared entries
are retained, navigation has one replaceable pending request, failed reads back off
for five seconds, and shutdown never waits for network I/O. A pending result keeps
the cloud curtain or previous scene animating. Cache keys include photo metadata;
completed work is retrieved by its own key so an old navigation request cannot
replace the selected photo. Product catalogue image loading remains synchronous.

Fixed button artwork and common loading labels are warmed during startup. The flash
uses a lookup table verified against masked paste for all 243 intensities. Its visual
fade is deliberately shortened from 550 to 180 ms, and the full-preview squeeze is
removed. The scene underneath the closing clouds freezes once at shutter activation;
clouds and flash continue animating, and camera preview decoding resumes on return.
This changes shutter presentation, not capture pixels or exposure settings.

Full local suite: 158 passed, 2 skipped. A real AI capture with background photo
preparation reached review in 20.965 seconds after shutter release; busy feedback
appeared after 48 ms. That real capture preceded the final short-flash/frozen-scene
changes. Those final changes were tested with a controlled transition, not another
server generation.

With short flash but a live underlying scene, the first two shutter seconds had 36
completed callbacks, median 41.10 ms, p95 79.51 ms, max 86.95 ms. Freezing the underlying
scene yielded 45 callbacks, median 31.55 ms, p95 47.70 ms, max 54.50 ms. These are
sequential single runs, not confidence intervals. Review transition maximum remained
171.68 ms; startup also has a cold hitch. Neither is claimed fixed. No render failures
were logged in the controlled run. Raw logs: timing-short.log and timing-freeze.log.

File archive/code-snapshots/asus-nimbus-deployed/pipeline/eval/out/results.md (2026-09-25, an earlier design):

Mean CIEDE2000 vs. true grade (lower is better)

| grade | none | oracle | mkl_direct | neutral_fit | neutral_diffusion |
|---|---|---|---|---|---|
| teal_orange | 8.91 | 0.66 | 19.92 | 13.86 | 15.23 |
| warm_film | 7.91 | 0.61 | 17.38 | 7.98 | 13.67 |
| cool_matte | 8.63 | 0.68 | 15.37 | 7.54 | 13.18 |
| punchy_warm | 7.06 | 0.54 | 21.83 | 11.84 | 17.38 |
| cross_process | 11.40 | 0.63 | 19.96 | 12.35 | 14.70 |
| mono_selenium | 14.56 | 2.39 | 15.69 | 15.35 | 17.44 |
| moody_green | 4.28 | 0.75 | 19.37 | 7.10 | 16.19 |
| **mean** | **8.96** | **0.89** | **18.50** | **10.86** | **15.40** |

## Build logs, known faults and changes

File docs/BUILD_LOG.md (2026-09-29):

# Building Nimbus

Nimbus started as loose electronics on a table and ended the weekend as a
working camera people could use at HackMIT. This page documents the physical
build; the software architecture and measured performance are covered in the
[design notes](DESIGN.md).

## 1. Sensor electronics on the bench

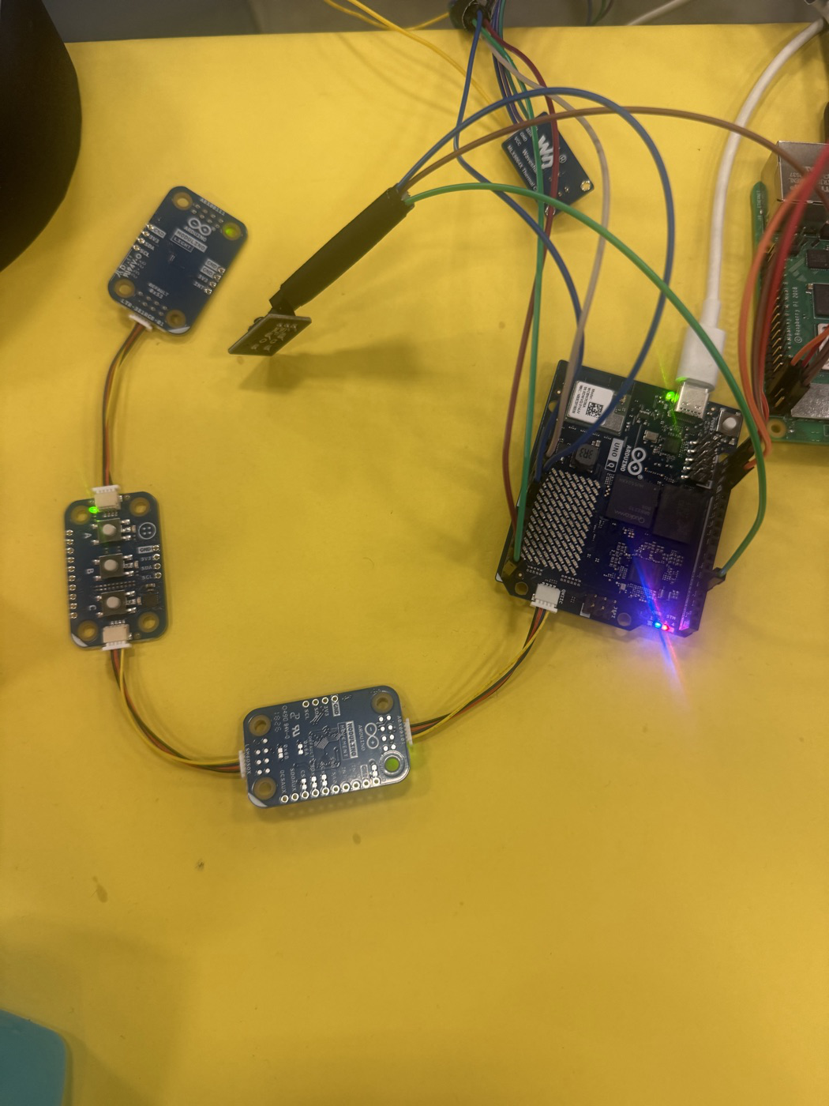
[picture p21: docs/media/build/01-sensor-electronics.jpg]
Sensor boards and wiring laid out for bench testing


We began by testing the sensor and control boards individually, before there
was an enclosure. Keeping everything accessible made it possible to verify
power, cabling, and readings independently. This also exposed the practical
side of the build early: several failures that looked like software problems
were actually power, USB, or wiring problems.

## 2. Raspberry Pi and Arduino integration

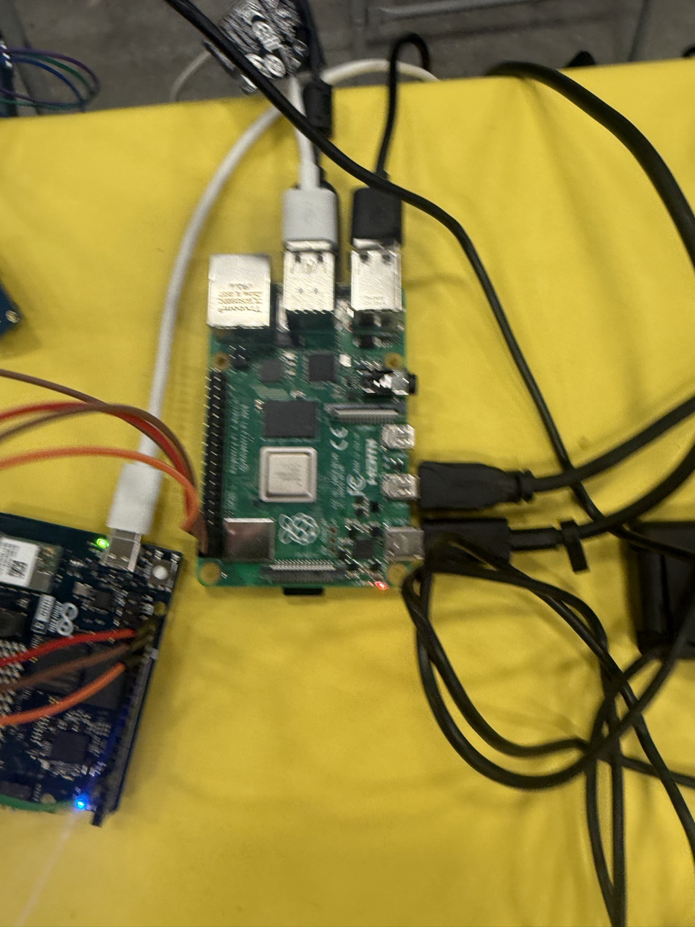
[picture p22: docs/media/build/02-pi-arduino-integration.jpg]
Raspberry Pi and Arduino hardware connected during integration


The Raspberry Pi 4 became the main device computer, responsible for the camera,
touchscreen, and application interface. The Arduino UNO Q supplied thermal
readings and physical-control input. The Pi forwarded captures and metadata to
the separate ASUS GPU computer for generation, so the device could remain a
portable front end instead of carrying the full model locally.

## 3. Building the first enclosure

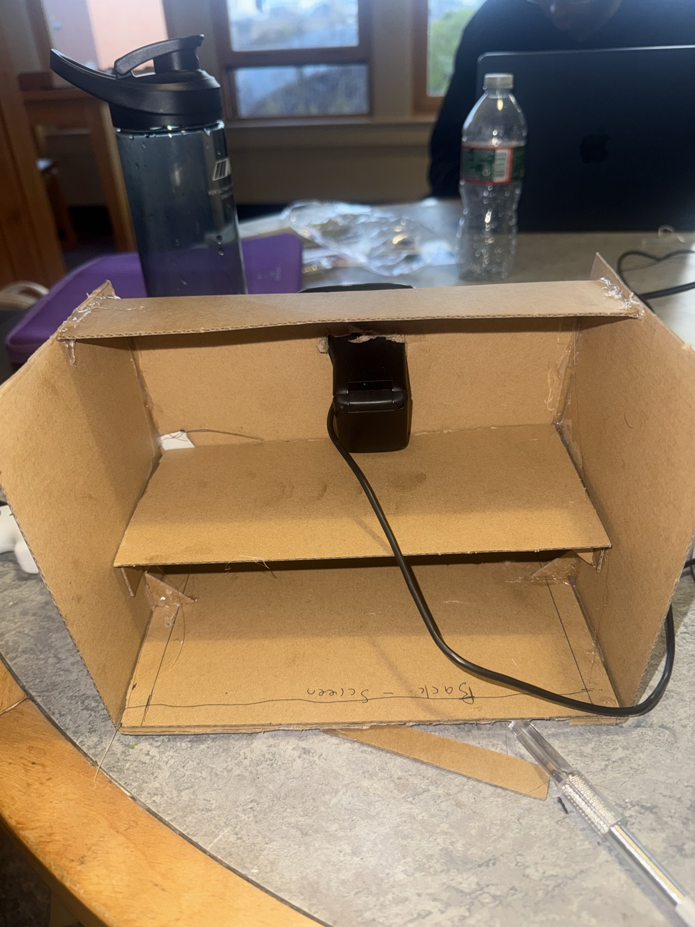
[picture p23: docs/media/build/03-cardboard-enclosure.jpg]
Cardboard enclosure with electronics being fitted inside


The event enclosure was built from cardboard and hot glue because it could be
cut and changed immediately as the hardware layout evolved. An internal shelf
separated the screen from the boards, the webcam was mounted at the front, and
the sides remained accessible for cooling, power, and last-minute wiring. The
goal was not a polished shell yet; it was a rigid prototype that could survive
continuous handling at the booth.

## 4. Touchscreen interface on the assembled rig

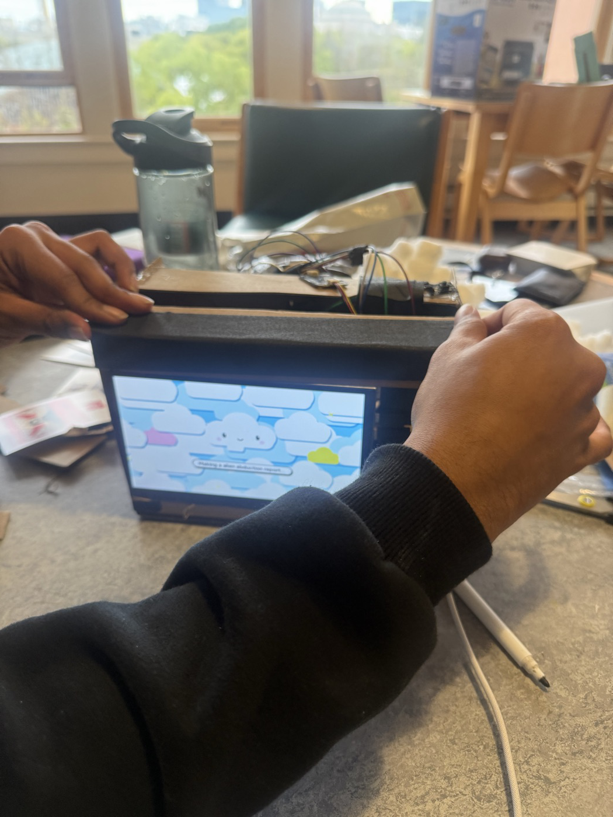
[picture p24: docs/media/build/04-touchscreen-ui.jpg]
Nimbus touchscreen running on the integrated cardboard prototype


With the screen, webcam, Pi, controls, and sensor wiring in one body, we could
test the complete interaction on the actual device. The touchscreen provided
the live viewfinder, touch-to-start screen, capture and review flow, gallery,
and shopping controls. Testing on the rig also revealed UI stalls that were not
obvious on a development laptop, leading to the background camera reader,
cached artwork, asynchronous review preparation, and SDL2 presenter described
in the [performance notes](../device/FRAME_PACING_RESULTS.md).

## 5. Working HackMIT prototype

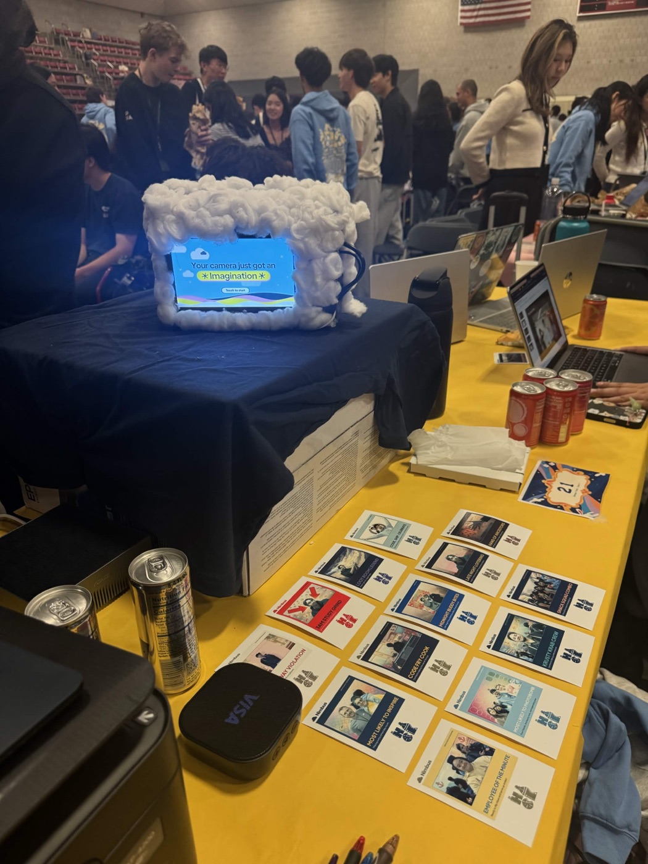
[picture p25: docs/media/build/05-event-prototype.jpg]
Nimbus operating at the HackMIT project booth


By the demo, Nimbus could capture a person, send the image to the GPU pipeline,
show the generated result on its touchscreen, retain searchable metadata, and
share or print the output. The cotton cloud covering was added around the
cardboard structure after the electronics and interface were working. It gave
the prototype its final character without hiding that it was a weekend build.

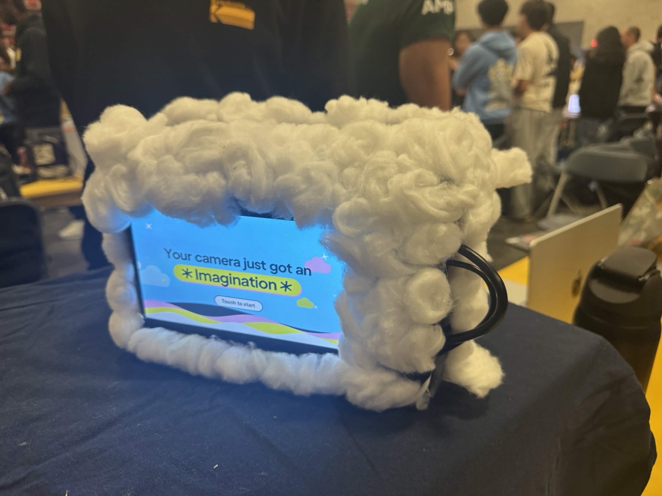
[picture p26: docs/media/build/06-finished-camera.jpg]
Close view of the completed cloud camera


## 6. From event prototype to printable enclosure

The cardboard build established the real component arrangement and cable
constraints. After the event, those measurements were carried into a modular,
3D-printable enclosure with a removable roof, replaceable front, electronics
shelf, service access, and dedicated mounts for the Raspberry Pi, UNO Q,
screen, webcam, and battery.

| Assembled concept | Internal layout |
|---|---|
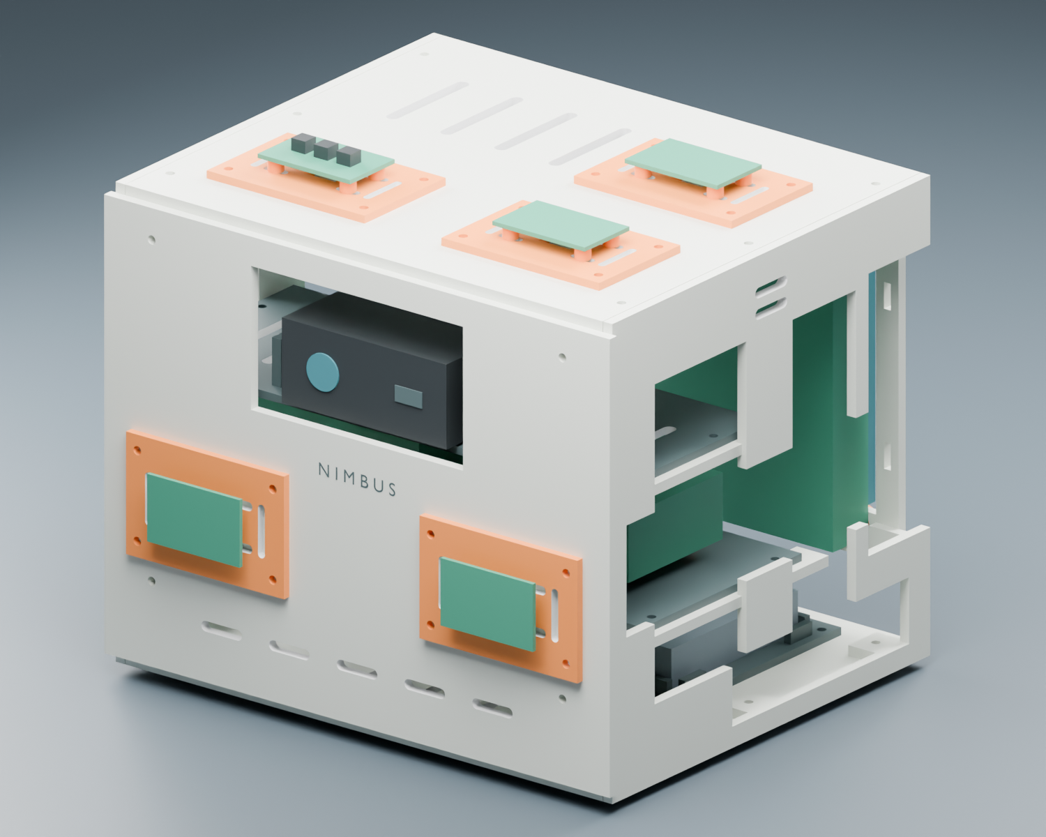
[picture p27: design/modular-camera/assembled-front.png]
Front render of the printable Nimbus enclosure
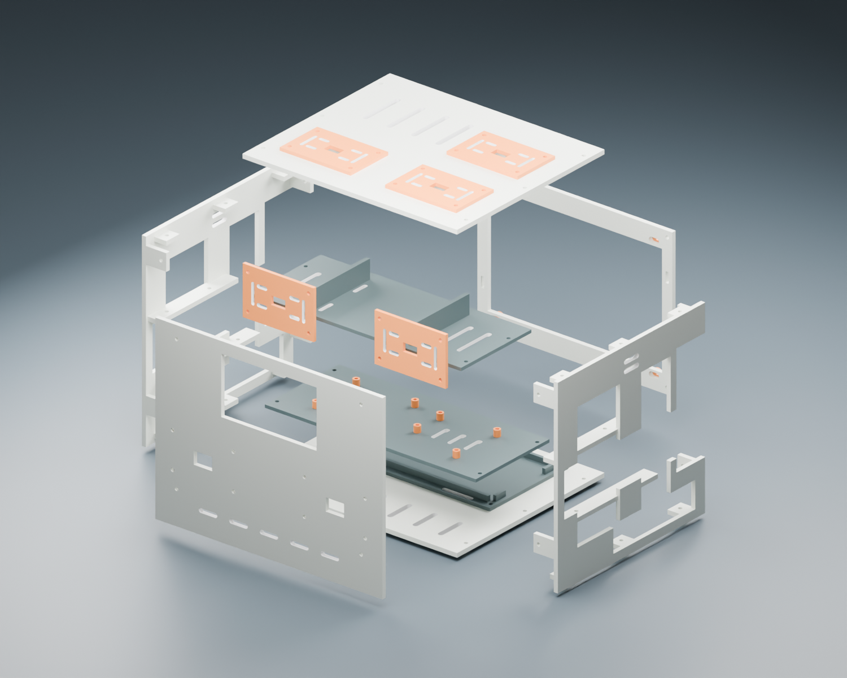
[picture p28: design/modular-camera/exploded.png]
Exploded render showing the modular enclosure parts
|  |  |

The printable design and its limitations are documented in
[the enclosure README](../design/modular-camera/README.md). The CAD is a design
iteration based on the working prototype; it should not be presented as a
fully printed and hardware-validated replacement until that physical build has
been completed.

## What the physical build taught us

- Validate camera, display, touch, sensors, and power independently before
  debugging the full stack.
- A distributed prototype needs explicit recovery paths for both USB devices
  and the Pi-to-GPU network connection.
- UI performance must be measured on the target hardware, not inferred from a
  laptop run.
- A fast, editable enclosure is valuable during integration. Precise CAD makes
  more sense after the real cable and component constraints are known.

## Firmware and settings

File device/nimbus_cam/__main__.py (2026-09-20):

"""Run the camera.

    python -m nimbus_cam --mac                       screen + voice + webcam + simulated sensors
    python -m nimbus_cam --mac --image photo.jpg     a still instead of the webcam
    python -m nimbus_cam --mac --text                type to the camera in the terminal (Muse, no mic)
    python -m nimbus_cam --mac --script "take_photo; search_photos query=fog; photo_details"
                                                      run tools with no screen or voice (tests)
    python -m nimbus_cam                             on the UNO Q (sensors over the Bridge)
"""

from __future__ import annotations

import argparse
import json
import os
import shlex
import threading

from . import keys
from .app import CameraApp
from .hw import Camera, MacSensors
from .library import open_library


def run_script(app: CameraApp, script: str) -> None:
    """Tools separated by ';'. Extra steps for tests: fog, heat, clear (simulated air), wait (for tagging)."""
    for step in filter(None, (s.strip() for s in script.split(";"))):
        name, *args = shlex.split(step)
        if name in ("fog", "heat", "clear"):
            if not hasattr(app.sensors, "fog"):
                print("> (real sensors: nothing to fake)")
                continue
            app.sensors.fog(name == "fog")
            app.sensors.heat(name == "heat")
            print(f"> air: {name}")
            continue
        if name == "wait":
            app.wait_for_tags()
            continue
        params = dict(a.split("=", 1) for a in args)
        print(f"> {name} {params}")
        print(json.dumps(getattr(app, name)(params), indent=2))
    app.wait_for_tags()


def main() -> None:
    ap = argparse.ArgumentParser(prog="nimbus_cam")
    ap.add_argument("--mac", action="store_true", help="simulated sensors")
    ap.add_argument("--pi", action="store_true", help="the Pi rig: thermal over I2C, webcam, webcam mic")
    ap.add_argument("--image", help="use a still instead of the camera")
    ap.add_argument("--camera", type=int, default=int(os.environ.get("NIMBUS_CAMERA", "0")))
    ap.add_argument("--local-library", action="store_true", help="skip Elasticsearch")
    ap.add_argument("--server-real", action="store_true", help="render Real on the server, not here")
    ap.add_argument("--script", help="run tools and exit")
    ap.add_argument("--text", action="store_true", help="type to the camera instead of talking")
    ap.add_argument("--no-voice", action="store_true")
    args = ap.parse_args()

    camera = Camera(args.camera, args.image)
    try:
        if args.pi:
            from .hw import PiSensors
            sensors = PiSensors(camera)
        elif args.mac:
            sensors = MacSensors()
        else:
            from .hw import BridgeSensors
            sensors = BridgeSensors()
        app = CameraApp(sensors, camera, open_library(not args.local_library),
                        render_locally=not args.server_real)
        print(f"[camera] library: {app.library.kind} · keys: {keys.status()}")

        if args.script:
            run_script(app, args.script)
            return

        from .ui import Screen
        from .tagger import prepare_capture_client
        prepare_capture_client()
        voice = None
        if not (args.no_voice or args.text):
            try:
                from .voice import Voice
                voice = Voice(app)
            except Exception as e:
                print(f"[voice] off: {e}")
        screen = Screen(app, voice)
        if args.text:
            from .voice import text_session
            threading.Thread(target=text_session, args=(app,), daemon=True).start()
        try:
            screen.run()
        finally:
            if voice:
                voice.close()
    finally:
        camera.close()


if __name__ == "__main__":
    main()

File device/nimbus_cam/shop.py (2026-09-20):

"""Shop: photograph a thing, the camera names it exactly, finds it for sale, and you buy it with Visa.

Three steps, each honest about what is real:

    identify(jpeg)   Muse Spark looks at the photo and names the product (brand, name, variant, size).
    find(product)    A live search: Open Food Facts for food and drink (the exact product, size and image)
                     and a web search for the rest; Muse turns the results into one to three offers with
                     merchant, price and link. No keys, nothing pre-canned.
    checkout(offer)  Payment. With Visa Developer sandbox credentials in the Keychain it is a real call to
                     the sandbox (Visa Direct pull-funds); otherwise `SimulatedVisa` approves it locally and
                     says so on the receipt. Nothing here ever moves real money.

Results are cached beside the photo (shop.json) so a second "what is this" costs nothing.
"""

from __future__ import annotations

import json
import os
import random
import time
from dataclasses import asdict, dataclass, field
from pathlib import Path

import httpx
from jwcrypto.common import json_encode

from . import keys, tagger

IDENTIFY_PROMPT = """Name the thing in this photograph as precisely as a shop listing would, and suggest what a
shopper who wants it might also buy.
Reply with JSON only:
{"name": "<product name as sold, e.g. 'Red Bull Energy Drink'; for a prepared dish its name, e.g. 'chicken pad thai'>",
 "brand": "<brand or null>",
 "variant": "<flavour, colour, model or size, e.g. '8.4 fl oz can', or null>",
 "category": "<one of: dish, food, drink, electronics, clothing, book, toy, sports, beauty, home, other>",
 "cuisine": "<for a dish: the cuisine word a restaurant listing would use, e.g. pizza, thai, ramen, burger, sushi, mexican; else null>",
 "confidence": <0 to 1>,
 "search_query": "<the exact words to search a shop for it>",
 "related": [{"name": "<a related product>", "search_query": "<words to search for it>",
              "why": "<'alternative' | 'goes with' | 'ingredient' | 'make it at home'>"}]}
category "dish" is cooked food on a plate or in a bowl (order it for delivery); "food" is a packaged
grocery item. Give 2 or 3 related products: for a dish, a way to order it and its key ingredient or a kit
to make it; for a drink, its other flavour and a snack; for a gadget, its accessory.
If there is no buyable product, use confidence 0, describe what is there in name, and related = []."""

OFFERS_PROMPT = """A shopper photographed: {product}. They may also want the related items listed below.
For each item there are live search results. Pick the results that sell exactly that item and turn them
into offers. Reply with JSON only:
{{"offers": [{{"item": <item number>, "merchant": "<store name>", "price": <number USD>,
              "est": <true if the price is not in the result text>, "url": "<the result url, exactly>"}}]}}
Keep it short: no other fields, no prose.
Up to 3 offers for item 0 and 1 or 2 for each other item, best first within an item (a single unit beats a
case or multipack, a listed price beats an estimate, a known US retailer or delivery service beats a
marketplace). If a listing is a multipack, say so in the title ("24-pack") and give the pack price.
Results marked "nearby restaurant" are real places near the shopper: for a dish, make an offer per place with
the restaurant as merchant and your best estimate of the dish's price there
(estimated true); put the nearest-sounding or best-known first. When the result gives no price, put
your best estimate of the usual US price for that item and set estimated to true. Skip an item with no match.

{results}"""


@dataclass
class Product:
    name: str
    brand: str | None = None
    variant: str | None = None
    category: str = "other"
    confidence: float = 0.0
    search_query: str = ""
    image_url: str | None = None      # from Open Food Facts when it knows the product
    related: list = field(default_factory=list)    # [{"name", "search_query", "why"}]
    cuisine: str | None = None        # for a dish: what nearby places are tagged with

    def label(self) -> str:
        name = self.name if not self.brand or self.brand.lower() in self.name.lower() else f"{self.brand} {self.name}"
        return f"{name}, {self.variant}" if self.variant and self.variant.lower() not in name.lower() else name


@dataclass
class Offer:
    merchant: str
    title: str
    url: str
    price: float | None = None
    currency: str = "USD"
    estimated: bool = False           # the price was not on the listing; Muse's guess at the usual one
    item: str = ""                    # what this offer is for: the product itself or a related item
    why: str = "this"                 # "this" | "alternative" | "goes with" | "ingredient" | "make it at home"
    image_url: str | None = None      # a catalogue picture of the item

    def price_text(self) -> str:
        if self.price is None:
            return "price on the page"
        return f"~${self.price:.2f}" if self.estimated else f"${self.price:.2f}"


@dataclass
class Receipt:
    approved: bool
    amount: float
    currency: str
    merchant: str
    last4: str
    auth_code: str
    transaction_id: str
    network: str                      # "Visa sandbox" or "simulated Visa"
    when: str = field(default_factory=lambda: time.strftime("%Y-%m-%dT%H:%M:%S%z"))
    message: str = ""


# ---------------------------------------------------------------------------------------------
# identify


def identify(jpeg: bytes) -> Product:
    client = tagger._client()
    if client is None:
        raise RuntimeError("no Muse key: the camera cannot name the product")
    r = client.chat.completions.create(model=tagger.MODEL, max_tokens=1200, reasoning_effort=tagger.REASONING,
                                       messages=[{"role": "user", "content": [
                                           {"type": "text", "text": IDENTIFY_PROMPT},
                                           {"type": "image_url", "image_url": {"url": tagger._data_url(jpeg)}}]}])
    d = _json(r.choices[0].message.content or "")
    related = [{"name": str(x.get("name", ""))[:60], "search_query": str(x.get("search_query") or x.get("name", ""))[:120],
                "why": str(x.get("why") or "goes with")[:20]}
               for x in (d.get("related") or []) if isinstance(x, dict) and x.get("name")][:3]
    return Product(name=str(d.get("name") or "something")[:80], brand=_opt(d.get("brand")),
                   variant=_opt(d.get("variant")), category=str(d.get("category") or "other").lower(),
                   confidence=float(d.get("confidence") or 0), search_query=str(d.get("search_query") or "")[:120],
                   related=related, cuisine=_opt(d.get("cuisine")))


# ---------------------------------------------------------------------------------------------
# find
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

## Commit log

2026-09-19 lookcam: voice-first camera that photographs the air
    - pipeline: subject-preserving capture (Real / Sensed air / New world), sensor
    effects, web weather, verified-subject proof, API on the GPU box
    - device: camera app with ElevenLabs push-to-talk, Muse Spark tools and vision
    tagging, Elasticsearch hybrid search, Instagram, QR send-to-phone
    - docs: design, API contract, demo renders
2026-09-19 Move to nimbus.akvaithi.page; Instagram via Instagram Login
    - The API is served at nimbus.akvaithi.page (the old lookcam hostname still
    routes, for links already out). QR codes and defaults use the new one.
    - expose_api.ps1 takes -HostName and no longer aborts on cloudflared's stderr.
    - Instagram posting uses graph.instagram.com with a single token; the account
    id is looked up from it. `python -m nimbus_cam.instagram` checks the token.
    [app.py, instagram.py]
2026-09-19 Mac launcher; wait for the macOS camera permission prompt
    run-mac.command starts Nimbus from Terminal (which macOS can ask for camera and
    microphone access) and brings up Elasticsearch. The camera now retries for 30 s
    while the permission prompt is on screen instead of failing on the first open.
    [hw.py]
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2026-09-19 Souvenir mode, motion -> blur, and the Pi rig's sensors
    - Dial 3 "Souvenir": Muse names the keepsake the scene deserves (a football ->
    a trading card, noodles -> a ramen packet), klein paints the surroundings as
    that artwork, and a frame carries the title and the readings. The subject is
    verified untouched before the frame goes on.
    - The sensor map now matches the sketch: lighting -> grain, motion -> blur,
    temperature -> hue, humidity -> diffusion. Motion blur is new.
    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
2026-09-19 Run on the Pi rig: real sensors, and stop shadowing stdlib secrets
    - nimbus_cam/secrets.py -> keys.py: a module of that name next to the app broke
    numpy on the Pi (numpy.random imports the stdlib secrets).
    - Readings are cast to plain floats; numpy scalars do not survive json.dumps.
    - README: installing and running on the Pi, including libportaudio2 for the mic.
    Verified on the Pi: temperature and motion from the MLX90640 over I2C, light
    from the camera, sound from the webcam mic, humidity and wind from the web, and
    a full Real capture rendered on the Pi itself.
    [__main__.py, agent.py, hw.py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]
2026-09-19 Add modular camera CAD R01 and printable package
    [01_rear_screen_frame.stl, 01_screen_frame_192x140x4.stl, 02_base.stl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]
2026-09-20 Nimbus on the Pi's panel: fullscreen UI sized to the screen
    The screen now takes its size from the display (NIMBUS_FULLSCREEN=1) instead of
    a fixed 800x480 window, so it fills the 1024x600 touch panel.
    Running on the rig: viewfinder, the four modes, and live readings from the
    thermal array, camera and microphone, with humidity and wind from the web.
    [ui.py]
2026-09-20 Run the GPU work on the ASUS GB10
    The rig cannot be on ZeroTier and the tailnet at once, and both the Pi and the
    ASUS sit on the venue wifi, so the image processing moves off the Windows box.
    - New `gb10` backend profile: klein fp8 with the fp4 text encoder that box has.
    - The Nimbus API runs there against its local ComfyUI, generating at 2 MP with
    no upscaler (the 128 GB GB10 does not need one).
    - Verified: Pi camera -> ASUS -> subject unaltered, 32 s end to end.
2026-09-20 Touch controls on the panel, and pick the rig's mic and speaker by name
    - The screen now has touch buttons (mode, shutter, hold-to-talk, photos; and
    back/prev/next/phone/post on a photo) calling the same functions as the keys
    and the voice agent.
    - Audio devices are chosen by name (NIMBUS_MIC / NIMBUS_SPEAKER): on the Pi the
    mic is the webcam and the speaker is the headphone jack, neither of which is
    the system default. Verified: tone out, 1 s recorded in.
2026-09-20 Physical buttons: shutter, mode and push-to-talk on GPIO
    The three buttons from the sketch wire between a pin and ground (GPIO17/27/22 by
    default, NIMBUS_PINS to move them, NIMBUS_GPIO=1 to enable). They call the same
    functions as the touch screen, the keys and the voice agent, so the camera has
    one set of actions reachable four ways. Armed and verified on the rig.
2026-09-20 One sensor-driven mode, plus Souvenir
    The dial had four positions; only one of them mattered. Nimbus now always
    repaints the surroundings as the air the camera measured and puts the sensor
    effects on top, and Souvenir turns the scene into the keepsake it deserves.
    With no GPU reachable the shutter still works: the camera renders the effects
    on its own board and says so.
    Also: CLAUDE.md with the findings that cost hours (Muse needs
    reasoning_effort=minimal or replies come back empty; never name a module
    secrets.py; the Pi's audio devices are not the defaults; X on a bare VT from
    SSH does not work), a handoff describing what runs where, and the READMEs and
    API docs updated for two modes.
    Co-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
    [__main__.py, agent.py, app.py]
2026-09-20 Deployed the two-mode build; GPU first, camera as fallback
    - The camera always posts to the GPU server; only when it is unreachable does
    Nimbus mode render the sensor effects on the Pi. The first cut had that the
    wrong way round (verified from the rig: both modes now render on the GB10).
    - ASUS: ComfyUI, the Nimbus API and Elasticsearch come back from a user
    @reboot crontab (no sudo there). Elasticsearch runs from its tarball.
    - Pi: keys persist in /etc/nimbus.env; search uses Elasticsearch on the ASUS.
    - Handoff and CLAUDE.md updated to the deployed state.
    [app.py]
2026-09-20 UNO Q sketch with buttons over I2C, and Shop: photo → product → Visa checkout
    The UNO Q is reflashed from its own Linux over ADB: thermal frames as before plus
    command 0x07 for the buttons on D2–D13 (shutter = D4; the rest get named from the
    log). The Zephyr Wire cannot do a repeated start, so the MLX90640 driver is patched
    to read through Zephyr's i2c_write_read.
    Shop: Muse names the product, a live search finds real listings, and checkout is
    simulated unless Visa sandbox credentials exist. Two new agent tools, a SHOP button,
    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
2026-09-20 Two camera modes: AI Camera (fifty formats, Muse picks) and Visa Buy
2026-09-20 AI Camera: the model renders only the given headline; no figures; webcam at 30 fps MJPG with capped exposure
2026-09-20 Portrait capture, wordless artwork with a big frame headline, 1.5 MP renders
2026-09-20 Screen: a photo the camera has no file for is fetched or greyed, never a stalled tick
    [ui.py]
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2026-09-20 Visa Buy shoots plain; AI Camera auto-posts the square photo alone; POSTED badge, mode hints, best-offer highlight
2026-09-20 Printing: polaroid prints on the Epson, a dev print page, and a PRINT button
    pipeline: nimbus/printing.py (CUPS hand-off, opt-in via NIMBUS_PRINTER; one job
    per copy since the XP-4200 ignores `copies` over USB; draft/normal/high quality),
    nimbus/polaroid.py (template-based polaroid layouts: four-up on 4x6, single and
    full-bleed on 3x4; Nimbus and HackMIT logos filled with the photo's dominant
    colour; cutting-guide sheet), nimbus/print_dev.py (localhost dev page with Print,
    Print lines, copies and speed), GET /printer and POST /captures/{id}/print.
    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
2026-09-20 Voice: notice a session thread that dies before its first message (credit refusal) and say why
2026-09-20 Pi print button: one full-bleed polaroid on the 3x4 page, draft quality
    The camera named no layout, so the API printed its default, four polaroids on a
    4x6 sheet. It now asks for layout=polaroid1full on 3x4 at draft quality (env
    NIMBUS_PRINT_LAYOUT / NIMBUS_PRINT_SIZE / NIMBUS_PRINT_QUALITY override); the QR
    card still prints as it is on 4x6.
2026-09-20 Brand palette and Plus Jakarta Sans; square AI Camera print without the sensor line; sensors shape the AI prompt; product image and Visa terminal animation in Shop; dB fallback
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2026-09-20 Camera screen: the Nimbus look (sky, clouds, waves, sticker buttons) with animation
    skin.py draws every screen in the site's style at 1024x600 with springy motion:
    drifting clouds and waves, a scrolling sensor ticker, tactile pill buttons with
    ripples, polaroid-style review, a QR card, the shop offers, the Visa card and
    receipt, the orbiting loading ring, toasts, touch puffs and a boot splash. Layout,
    touch targets and behaviour are unchanged; ui.py now only owns the window, touch
    and state. Shapes are drawn once and cached, so frames cost 13-41 ms on a Pi 4.
    design/pi-ui/mockup.html is the interactive mockup it was built from.
    [skin.py, ui.py]
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2026-09-20 Loading screens: a curtain of clouds closes over the screen and opens when done
    Replaces the blurred overlay with orbiting dots and progress bar. On any wait, clouds
    converge from the edges (outer first, then in), the scene shrinks to an iris that
    closes, and a cloud mascot with blinking eyes appears with the status line, sparkles
    and small clouds drifting past. Touching the curtain makes nearby clouds wobble. When
    the work finishes the iris opens from the centre and the clouds part. It always closes
    fully before opening, so a very short load does not flicker. Buttons under the curtain
    do not respond while it is closed.
    [skin.py, ui.py]
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2026-09-20 Camera found by name (/dev/v4l/by-id), not by index: a USB reset moved the C270 to video1
    [hw.py]
2026-09-20 Harden camera reader shutdown, stale frames and capture failures
    [__main__.py, hw.py]
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2026-09-20 Readings: only finite numbers (a NaN dB after a USB reset broke indexing)
    [hw.py]
2026-09-20 Shutter exposure cap keeps the brightness: gain scales with the shortened exposure
    [hw.py]
2026-09-20 Skip hidden V4L2 preview decoding and preserve fresh-frame transitions
    [hw.py, skin.py, ui.py]
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2026-09-20 Cache fixed-opacity background clouds
    [skin.py]
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2026-09-20 Prepare fixed capture artwork before shutter interaction
    [frame_pacing.py, skin.py]
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2026-09-20 Avoid rasterizing caption prefixes that clearly fit or stay hidden
    [skin.py]
2026-09-20 Avoid stale capture connections and attribute transport failures
    [app.py, capture_http.py]
2026-09-20 Preserve existing HTTP error handlers for capture requests
    [capture_http.py]
2026-09-20 Prewarm fixed preview artwork before interaction
    [skin.py]
2026-09-20 Keep search embeddings across Pi reboots and load cached models offline
    [library.py]
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2026-09-20 Idle screen: the splash design (waves, logo, headline, stars) with a close-on-tap cloud bridge
    Takes the Pi's newer skin.py (wake-frame cache, control caching) and replaces its
    wall-of-clouds idle scene with the mockup splash plus twinkling stars and a
    "Touch to start" pill. A tap now closes the clouds over the idle sky and then
    parts them onto the camera, so there is no hard cut.
    [skin.py]
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
